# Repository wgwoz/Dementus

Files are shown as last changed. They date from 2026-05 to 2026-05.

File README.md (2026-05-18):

# Dementus
Dementus jest to projekt i prototyp urządzenia służącego do pomocy osobom z chorobami wieku starczego i po wypadkach z funkcjami umysłowo-motorycznymi. Był on realizowany w celu zgłoszenia go do Olimpiady Innowacyjności Technicznej w Mechatronice, gdzie w 2025 roku zajął 2 miejsce. 

Readme będzie stopniowo rozwijane, celem dokumentacji projektu. w międzyczasie zapraszam do dokumentacji w wersji pdf, która była utworzona na cele konkursu.

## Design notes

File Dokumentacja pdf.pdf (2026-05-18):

# DEMENTUS

## Projekt urządzenia podtrzymującego i regenerującego funkcje motoryczno-poznawcze

## Przygotowali:

Wiktor Gwoździewicz Zespół Szkół Elektronicznych Elektrycznych i Mechanicznych
Patrycja Nowak | I Liceum Ogólnokształcące im. Mikołaja Kopernika

## Pod opieką:

dr inż. Piotra Kamińskiego

Zaoraszamy również do obejżenia wideo prezentacji pod linkiem: https://drive.google.com/file/d/1-FGnG8ihYWgB2yMIkUJgleXV_v9-Wq1k/view?usp=sharing

## Spis Treści:

2) NIEPEŁNOSPRAWNOŚCI (UPOŚLEDZENIA) INTELEKTUALNE I ZABURZENIA

DEMENTUS

## Wstęp

## Cel pracy:

Aby wspomóc leczenie i rehabilitacje osób z różnego rodzaju zaburzeniami motoryczno-

poznawczymi, opracowaliśmy alternatywę dla aktualnie dostępnych na rynku tablic

sensorycznych. Nasze rozwiązanie, dzięki zastosowaniu nowoczesnych technologii, przy podejściu indywidualnym do pacjenta może przyczynić się do zwiększyć efektywność leczenia.

## Zakres pracy:

- Przeprowadzenie wywiadu środowiskowego wśród osób cierpiących na wstępne stadium choroby demencji, oraz wywiad z opiekunami osób cierpiących na demencję,
- Przedstawienie z jaki zaburzeniami motoryczno-poznawczymi możemy się spotkać wśród pacjentów,
- Przedstawienie Koncepcji projektu,
- Omówienie poszczególny elementów elektryczno-elektroniczno-mechanicznych wykorzystanych w naszym projekcie,
- Przedstawienie autorskiego kodu programu napisanego przez nas zapewniającego funkcjonalność „Dementusa”.

1

Wstęp

## Skrócony opis projektu:

Szanowni Państwo chcielibyśmy przestawić nasze unikatowe urządzenie, zwiększające motorykę pacjenta z zaburzeniami motoryczno-poznawczymi oraz co najistotniejsze podnoszące świadomość dla osób cierpiących na demencję.

Nasze projekt znamienity jest tym, że jest dedykowany indywidualnie dla pacjenta w zależności od jego preferencji. Takie podejście jest możliwe dzięki wykorzystaniu elementów elektroniczno-elektrycznych szerzej oraz szczegółowo omówionych w dalszej części pracy. Możliwość programowania oraz adaptacji kodu pod indywidualne potrzeby pacjenta. Sprawia że nasz projekt jest uniwersalny i niepowtarzalny. Większość wykorzystanych w projekcie ćwiczeń z pacjentem jest automatycznie w odpowiednim czasie wyjedzona z obudowy, a po skończonym ćwiczeniu chowana do obudowy. Ma to na celu zapewnienie odpowiedniej przestrzeni do wykonywania ćwiczenia. W obudowie znajdują się pełno silniczków, dźwigni wymagających sterowania, aby zapewnić płynnych ruch poszczególnych podzespołów.

Sercem „Dementusa” jest mikrokontroler Raspberry Pi PICO, który wykorzystując oba rdzenie kontroluje wszystkie moduły, kontroluje komunikacje po UART i SPI oraz na bieżąco monitoruje stan naładowania ogniw.

Dodatkowo zaprojektowaliśmy płytkę drukowaną, która zwiększa wytrzymałość fizyczną urządzenia, oraz pozwala na szybką wymianę modułów składowych

Ponadto wykorzystaliśmy w projekcie odtwarzacz mp3 DFPlayer mini, moduł karty SD, wyświetlacz LCD 1,8”, mostki H, drivery silników krokowych, silniki z wbudowaną przekładnią i przyciski z wbudowanym podświetleniem. Odczytuje sygnały analogowe i cyfrowe.

Szczegółowo elementy te zostały omówione w dalszej części pracy

2

Wykorzystanie kart SD z danymi pozwoliło na łatwą personalizację urządzenia do pacjenta.

Urządzenie posiada wewnętrzny akumulatory i możliwość ładowania za pomocą USB, powerbank .

Wykorzystanie druku 3d pozwoliło na szybkie prototypownie i wprowadzanie poprawek jak

i na tańszą produkcję. Zastosowanie centralnej płytki PCB z wszystkimi modułami montowanymi na goldpiny oraz zewnętrznymi elementami na wtyki JST pozwala na łatwy montaż i zmniejszenie kosztów naprawy ewentualnych uszkodzonych elementów podczas użytkowania.

Kolejność poszczególnych ćwiczeń na „Dementusie” (rodzaje ćwiczeń omówione w zasadzie działania urządzenia) jest dobierana losowo, natomiast czas trwania danego ćwiczenia w danym bloku jest nastawiany indywidualne dla poszczególnych pacjentów.

## Zasada działania urządzenia:

Nasze urządzanie w założeniu ma pomóc w maksymalnym stopniu spowolnić proces demencji. Wykonywanie kompleksowego bloku ćwiczeń ruchowo-umysłowych na naszym urządzaniu zapewni stymulację umysłu pacjenta co może przyczynić się opóźnienia demencji i tym samym zwiększy pamięć pacjenta . Nasze rozwiązanie techniczne znamienite jest tym, że jest dedykowane indywidualnie do pacjenta w zależności od jego preferencji tj. Dźwięków znanych pacjentowi, zdjęć prywatnych z przeszłości mających wywołać pozytywne myśli. Do konfiguracji naszego urządzenie niezbędne jest przeprowadzanie z pacjentem lub jego opiekunem wywiadu środowiskowego.

3

Wstęp

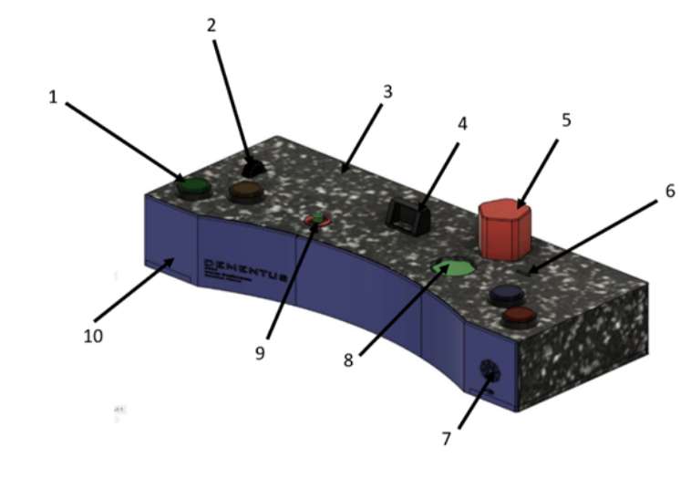
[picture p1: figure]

Dememtus 1- przyciski z wbudowanymi lampkami 4sztuki, 2-klikacz, 3-obudowa wykonana ze spieku, 4-wyświetlacz, 5-obrotowy wskaźnik zdjęć, 6-napinacz manualny, 7-głośnik, 8- spinner, 9 – skrzynia biegów 10-obudowa przednia

Przez wzgląd, że nasze urządzenie dedykowane dla osób we wstępnej fazie demencji, założyliśmy że korzystająca z naszego urządzenia osoba jeździ na wózku inwalidzkim lub będzie z niego korzystała w pozycji siedzącej. Mając powyższe na uwadze wszystkie zastosowane przyciski, drążki, dźwignie oraz manualne przyrządy do ćwiczeń, tak zostały rozmieszczone, aby w pozycji siedzącej był do nich swobodny dostęp. Na początku należy przeprowadzić z pacjentem wywiad w celu pozyskania informacji o jego zainteresowaniach, sytuacjach z życia, które przy wojują u pacjenta miłe wspomnienia. Na podstawie tych informacji zostają stworzone, pozyskane obrazy graficzne, oraz sygnały dźwiękowe.

4

Nasz pierwszy pacjent do testu urządzenia interesował się zwierzętami leśnymi (głównie ptactwem) dlatego stworzono bazę dźwięków wydawanych przez dzikie zwierzęta które usłyszymy w głośniku (7) z głośnika zostaną puszczone losowe głosy ptaków, gdzie zadaniem pacjenta będzie za pomocą obrotowego wskaźnika (5) na którym z boku będzie przymocowanych 5 zdjęć ptaków tak ustawić zdjęcie, aby wskazać odgłosy prawidłowego ptaka i potwierdzić wybór przyciskiem zielonym(1) to spowoduje że na wyświetlaczu 4 pokaże się informacja o prawidłowym bądź błędnym wskazaniu. Ma to na celu ćwiczyć koordynację ruchowo- dźwiękową oraz szukania zależności. Pragniemy w tym miejscu zaznaczyć że połączenie obrazu z dźwiękiem można zaprogramować dowolnie w zależności od preferencji pacjenta, dlatego tak istotny jest wywiad z pacjentem przed indywidualnym zaprogramowaniem „Dementusa” np. można połączyć dźwięki silnika samochodu z obrazkami konkretnych pojazdów (modeli) jeśli ktoś interesuje się motoryzacją itp. Kolejnym innowacyjnym rozwiązaniem w naszym urządzeniu jest możliwość losowego wyświetlania zdjęć z przeszłości pacjenta liczba zdjęć jaką możemy wgrać jest ograniczona tylko pojemnością karty pamięci celem nadrzędnym tego ćwiczenia jest wywołanie dobrych, pozytywnych wspomnień u pacjenta Tworząc bazę zdjęć bardzo istotne jest pozyskanie indywidulanych zdjęć dla każdego pacjenta. Zdjęcia będą wyświetlane losowo i przez pewien czas wyświetlane na wyświetlaczu (4) wraz z dźwiękiem muzyki relaksacyjnej. Ma to na celu wywołania, skoncentrowanie myśli pacjenta na pozytywnych wspomnieniach, aby choćby na chwilę oderwać się od otaczającej rzeczywistości. Kolejnym innowacyjnym elementem w naszym „Dementusie” jest dostarczenie pacjentowi rozrywki poprzez wciągnięcie pacjenta do gry polegająca na ćwiczeniu koordynacji ruchowo -wzrokowo-pamięciowej. Gra polega na losowo świecących się żarówkach w przyciskach (1) (do dyspozycji 4 przyciski z podświetleniem). Pacjent zapamiętuje kolejność zaświecania żarówek, a następnie jego zadaniem jest odtworzenie tej sekwencji poprzez naciskanie kolejnych przycisków w kolejności ich świecenia. To co istotne przyciski zostały tak rozmieszczone, aby pacjent musiał poruszać i podnieść całą rękę prawą bądź lewą zostało to wprowadzone celowo, aby zwiększyć motorykę pacjenta. Jest możliwość wyłączenia z obsługi konkretnych przycisków, jeżeli kondycja ruchowa pacjenta nie pozwala na swobodne naciśnięcie przycisku. Na początku świecą się 2 żarówki, jeśli poprawnie odtworzy się sekwencję to w dalszej kolejności randomowo świecą się 3 itd. aż do błędnej sekwencji wówczas ćwiczenie zaczyna się od nowa.

Następnym wprowadzonym przez nas rozwiązaniem jest badanie czasu reakcji pacjenta na sygnał świetlny. Odbywa się to w sposób następujący: losowo zaświeci się 1 żarówka w przycisku (1) z

5

Wstęp

czterech przycisków podświetlanych, następnie zadaniem pacjenta jest w jak najkrótszym czasie nacisnąć przycisk który się zaświecił. Program zlicza czas reakcji pacjenta i wyświetla wynik czasu reakcji na wyświetlaczu (4). Jako opiekunowie pacjenta jesteśmy w stanie sprawdzić jak szybka w danym dniu była reakcja pacjenta. Na podstawie tej informacji (czas reakcji pacjenta na bodziec) jesteśmy w stanie ocenić bieżącą kondycję pacjenta co może okazać się bardzo istotną wskazówką czy i jak choroba postępuje. Dzięki temu rozwiązaniu mamy porównanie jak pacjent poradził sobie z zadaniem w przeszłości. Umożliwi to również budowanie statystyk postępu pacjenta.

Kolejnym elementem w urządzeniu jest zaprojektowana przez nas atrapa skrzyni biegów (9), gdzie ćwiczy się koordynację ruchową poprzez właściwe wbicie biegu (urządzanie dzięki oprogramowaniu stworzonemu przez nas oraz wbudowanym głośnikom wydaje polecenie jaki bieg należy włączyć). Ponadto aby nie dezorientować pacjenta przy korzystaniu z „Dementusa” w monecie w kiedy nie korzysta się ze skrzyni biegów (9) chowa się ona do obudowy, zostało to zaprezentowane w filmiku.

Dalej, aby wzmocnić mięśnie pacjenta, jego chwyt dłonią zaprojektowaliśmy i wykonaliśmy zestaw linek (6) mocowanych na wale silniczka który możemy hamować. Ćwiczenie polega na wyciąganiu linki (wstążki) , której możemy regulować siłę oporu wyciągania, po wyciągnięciu linek można je wykorzystać do ćwiczenia zaplatania warkocza, lub ćwiczenia węzłów żeglarskich, wspinaczkowych w zależności od indywidualnych preferencji pacjenta. Po skończonym ćwiczeniu zestaw linek zostaje wciągniętych do obudowy.

Kolejnym elementem w naszym projekcie jest klikacz (2) ćwiczenie na klikaczu z założenia ma pobudzić krążenie w dłoni i palcach, przeprowadzając wywiad środowiskowy z pacjentami i ich opiekunami przed rozpoczęciem projektu. Wspominali o zaniku krążenia w palcach rąk, drętwieniu palców, dłoni. Mając powyższe na uwadze zaprojektowaliśmy ćwiczenie mające zaradzić pogłębianiu się tego zjawiska. Obrót palcem na klikaczu powoduje pobudzenie pracy mięśni, masowanie mięśni palców aby zwiększyć przepływ krwi. Klikacz (2) po skończonym ćwiczeniu chowa się (wjeżdża) do obudowy (3).

Do zwiększenia motoryki pracy dłoni zaprojektowano również spinner (8), który gdy nie jest używany znajduje się w obudowie (3), natomiast podczas pracy na nim wyjeżdża z obudowy. Spinner ma za zadanie głównie ćwiczyć ruch w nadgarstkach, przedramieniu oraz palców.

6

## O demencji i innych anormalnościach mózgu

## 1) DEMENCJA

Demencja (zespół otępienny) to grupa chorób mózgu, których wspólnym elementem jest utrata funkcji poznawczych. Według Światowej Organizacji Zdrowia demencję można zdefiniować jako zespół objawów wywołanych przez przewlekłą lub pogłębiającą się chorobę mózgu.

Demencja [16]

Otępienie różnicuje się ze względu na obszar objęcia:
- otępienie korowe: przeważają zaburzenia pamięci, zdolności wzrokowo – przestrzennych oraz funkcji językowych,
- otępienie podkorowe: przeważają spowolnienie toku myślenia oraz upośledzenie wykonywania bardziej złożonych czynności intelektualnych, przy czym funkcje językowe i umiejętności uczenia się pozostają dobrze zachowane. [1]

Możemy wyróżnić trzy poziomy demencji:
- otępienie lekkie, które cechuje się problemami w procesach poznawczych, aktywnie utrudniając osobie chorej wykonywanie codziennych czynności (chora osoba jest jednak w stanie samodzielnie funkcjonować);
- otępienie umiarkowane, przy którym samodzielne funkcjonowanie jest znacznie ograniczone, a osoba chora wymaga pomocy osób trzecich;
- otępienie głębokie, polegające na znacznym deficycie pamięci krótkotrwałej oraz zaburzeniach orientacji (osoba chora wymaga stałej opieki innych osób). [1]

7

O demencji i innych anormalnościach mózgu

Ryzyko zachorowania na demencję wzrasta wraz z wiekiem. Najczęściej dotyka ona osób po 65. roku życia, a bezpośrednią jej przyczyną jest choroba mózgu, do której doprowadzają procesy degeneracyjne w nim zachodzące.

Możliwe przyczyny i czynniki ryzyka zespołu otępiennego to:
- przebyte urazy, [1]
- problemy naczyniowe, [1]
- długotrwały, silny stres, [1]
- nieleczone choroby układu naczyniowego, [1]
- niska aktywność fizyczna i intelektualna, [1]
- nadużywanie alkoholu, [1]
- niski status społeczno – ekonomiczny, [2]
- izolacja społeczna, [2]
- niedobór witaminy D, [2]
- wysoki poziom białka C – reaktywnego, [2]
- upośledzenie słuchu, [2]
- cukrzyca, [2]
- depresja, [2]
- palenie tytoniu, [2]
- gen apolipoproteiny E. [2]

Rodzaje demencji
Najczęstsza forma demencji to choroba Alzheimera.[1] Jest ona spowodowana nieprawidłowym gromadzeniem się białek w komórkach mózgowych i wokół nich. W efekcie zmniejsza się liczba przekaźników chemicznych zdolnych do wysyłania sygnałów między neuronami. Poziom acetylocholiny jest szczególnie niski u osób dotkniętych tą chorobą.[3] Następuje stopniowe pogarszanie się wzroku, dotyku, słuchu, poczucia świadomości. Osoby chore jako jeden z pierwszych objawów najczęściej zauważają pogorszenie się pamięci. [1] Leczenie tej choroby polega na leczeniu objawów stosując odpowiednie leki. Bardzo istotne jest zapewnienie choremu

8

spokoju, komfortu i poczucia bezpieczeństwa. Ważne jest też stosowanie ćwiczeń umysłowych i pamięciowych. [34]

Otępienie czołowo – skroniowe (choroba Picka) występuje na skutek zmian w płatach skroniowych

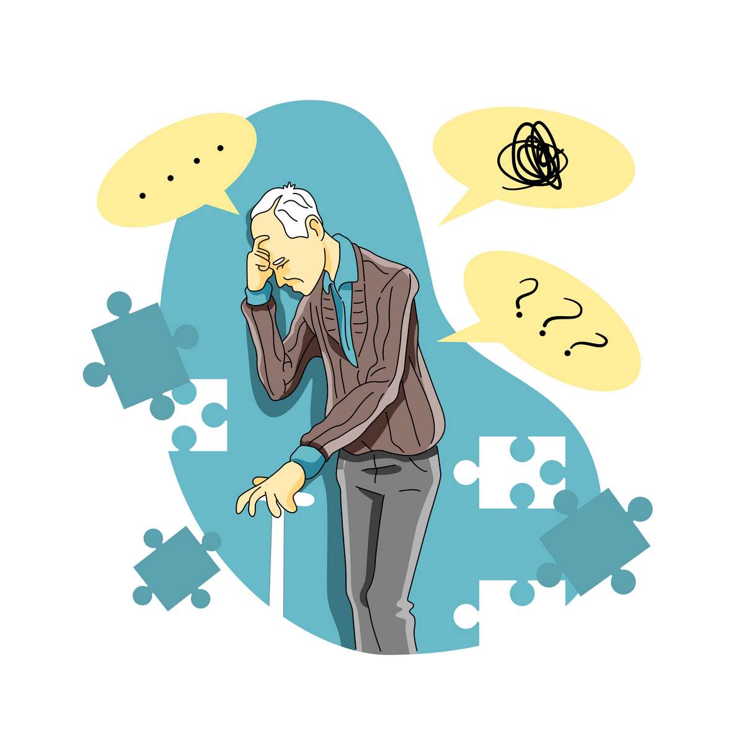
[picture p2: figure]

i czołowych mózgu.[3] W przypadku postaci czołowej schorzenia występują zaburzenia w obrębie zachowania i osobowości, a w przypadku postaci skroniowej – zaburzenia w obrębie wysławiania się. Często obie postacie występują jednocześnie. Osoby cierpiące na tę postać demencji mogą przejawiać zachowania agresywne, być nieuprzejme. Może również wystąpić stopniowa utrata zdolności zapamiętywania imion, trudności ze zrozumieniem wypowiedzi czy znaczenia poszczególnych słów.[1] Nie ma możliwości rozpoczęcia leczenia przyczynowego choroby, w związku z czym leczenie polega na łagodzeniu nieprzyjemnych i uciążliwych objawów chorobowych oraz ćwiczeniu umysłu i pamięci chorego. [35]

Demencja naczyniowa jest wywoływana przez uszkodzone naczynia krwionośne w mózgu, przez co niemożliwe jest dostarczenie odpowiedniej ilości krwi zawierającej tlen i składniki odżywcze do komórek mózgowych. Przyczyną tego rodzaju demencji może być udar. [3] Objawy mogą zostać zaobserwowane bezpośrednio po udarze lub w pewnym okresie po jego wystąpieniu. Charakterystycznym objawem jest znaczne pogorszenie się percepcji. Demencja naczyniowa często występuje w kombinacji z chorobą Alzheimera[1], a leczenie tych dwóch chorób wygląda bardzo podobnie. Przy demencji naczyniowej również stosuje się leczenie farmakologiczne oraz ćwiczenia umysłowe i pamięciowe. [36]

9

Otępienie czołowo-skroniowe [17]

O demencji i innych anormalnościach mózgu

Otępienie z ciałami Lewy’ego występuje gdy ciała Lewy’ego, czyli patologiczne białka, gromadzą się w mózgu, w wyniku czego niszczony jest ośrodkowy układ nerwowy. Jest to choroba postępująca, której charakterystycznymi objawami są drżenie kończyn, problemy z przełykaniem, upadki i halucynacje wzrokowe oraz koszmary senne.[3] Występują zaburzenia w poruszaniu się, zachowaniu i myśleniu. Często występuje w połączeniu z chorobą Parkinsona, Alzheimera i/lub demencją naczyniową.[1] W przypadku tej choroby wszystkie grupy symptomów wymagają zastosowania odrębnego leczenia obejmującego farmakoterapię oraz metody niefarmakologiczne (stymulacja poznawcza, ćwiczenia pamięci, trening orientacji w przestrzeni, rozwiązywanie krzyżówek, układanie puzzli itp.) [37]

Choroba Creutzfeldt-Jakoba jest powodowania przez priony. Jest śmiertelną chorobą mózgu, której pierwszymi objawami są pogorszenie pamięci, brak koncentracji i zmienione zachowanie. Choroba jest agresywna i gwałtowna – w późniejszych stadiach doprowadza do osłabienia kończyn, utraty wzroku i śpiączki.[1] Ważną rolę w opiece nad chorym odgrywa odpowiednia dieta. Jakość życia poprawiają również odpowiednie ćwiczenia intelektualne. [38]

Rodzaje demencji [18]

We wczesnych fazach choroby często jest ona trudna do wychwycenia zarówno przez osobę chorą, jak i jej najbliższe otoczenie. Bardzo ważna jest obserwacja seniorów i zwracanie szczególnej uwagi na pierwsze objawy ostrzegawcze, takie jak zapominanie o bieżących wydarzeniach, trudności z czynnościami i sytuacjami wcześniej nie sprawiającymi trudności, brak orientacji w

10 czasie i miejscu, gubienie przedmiotów, ogólne zmiany w osobowości,[1] zadawanie tych samych pytań w krótkich odstępach czasu, nagłe zmiany nastrojów.[3]

W przypadku zauważenia niepokojących objawów, należy zgłosić się do lekarza podstawowej opieki zdrowotnej. Lekarz zanalizuje stan pacjenta, a następnie skieruje do specjalisty lub do szpitala.[3] Nie istnieje lek, który wyleczy demencję – jest ona chorobą nieuleczalną. W przypadku tej choroby podaje się jedynie leki, które zwiększają poziom acetylocholiny – substancji przekaźnikowej w układzie nerwowym, która odpowiada m.in. za procesy pamięciowe.[4] Bardzo ważnym elementem leczenia jest również dbanie, aby osoba chora pozostawała aktywna intelektualnie poprzez ćwiczenia pamięciowe i umysłowe (krzyżówki, rebusy, czytanie książek).[1]

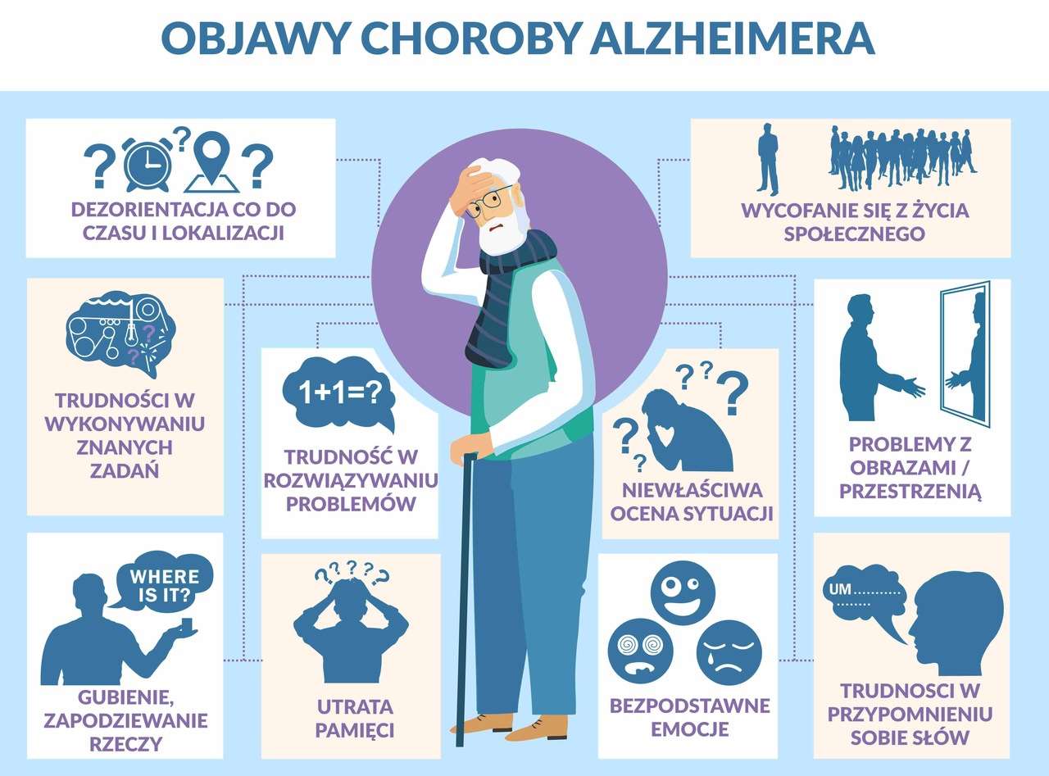
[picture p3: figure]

Objawy choroby Alzheimera [19]

## 2) NIEPEŁNOSPRAWNOŚCI (UPOŚLEDZENIA) INTELEKTUALNE I ZABURZENIA ROZWOJOWE

Niepełnosprawność intelektualna to zaburzenie rozwojowe, które polega na obniżeniu funkcji intelektualnych wraz z deficytem na polu zachowań adaptacyjnych.[5] Objawia się najczęściej trudnościami w nauce i porozumiewaniu się, wykonywaniu czynności dnia codziennego oraz zyskiwaniu kompetencji społecznych. [6]

11

O demencji i innych anormalnościach mózgu

Niepełnosprawność intelektualna [20]

Termin ,,upośledzenie umysłowe” jest uważane w środowisku psychologów i pedagogów za stygmatyzujący, pomimo że nazwa ta nadal oficjalnie funkcjonuje w medycynie. Uważa się, że utrwala ona negatywne stereotypy, w związku z czym apeluje się, aby w nazewnictwie pozamedycznym używać terminu ,,niepełnosprawność intelektualna”.[6]

Niepełnosprawność umysłową można badać pod kątem:
- kliniczno-medycznym: badane jest wtedy wrodzone bądź istniejące od wczesnego dzieciństwa obniżenie poziomu rozwoju intelektualnego, [6]
- psychologiczno-społecznym: badane są wtedy głównie konsekwencje dla umiejętności społecznych i interpersonalnych danej osoby oraz jej samodzielne funkcjonowanie w społeczeństwie. [6]

Klasyfikacja zaburzeń rozwoju intelektualnego:
- upośledzenie w stopniu lekkim:
Stanowi najłagodniejszą formę niedorozwoju umysłowego, odpowiada poziomowi inteligencji osoby w wieku 10 – 12 lat. Zdiagnozowane osoby mają zazwyczaj problem z pamięcią, abstrakcyjnym myśleniem, spostrzegawczością, wyobraźnią. Dominuje myślenie konkretno – obrazowe, występują problemy z myśleniem przyczynowo – skutkowym, porównywaniem. Proces socjalizacji przechodzi na ogół dobrze. Następuje opóźniony rozwój motoryczny: dzieci z lekkim upośledzeniem później uczą się siadać i chodzić. [5],[6]

12

- upośledzenie w stopniu umiarkowanym:
Odpowiada poziomowi inteligencji osoby w wieku 6 – 9 lat. Osoba upośledzona ma duże problemy z tempem uczenia się, skupieniem uwagi. Jest w stanie opanować jedynie podstawy pisania, czytania i liczenia. Rozwój motoryczny opóźniony, dziecko siada w wieku ok. 2 lat, chodzi w wieku ok. 3 lat. Osoba zdiagnozowana jest bardzo wrażliwa, słabo kontroluje swoje emocje. W zachowaniu występują skrajności: dziecko może być apatyczne, spokojne, niesprawiające żadnych problemów lub może być nadpobudliwe, nieposłuszne i niszczyć przedmioty. [5],[6]
- upośledzenie umysłowe w stopniu znacznym:
Odpowiada poziomowi inteligencji osoby w wieku 3 – 6 lat. Występują poważne problemy z motoryką, mówieniem, spostrzegawczością, pamięcią, koncentracją. Potrafi koncentrować się głównie na przedmiotach wyróżniających się np. kolorem lub służących do zaspokajania potrzeb. Nie w pełni kontroluje emocje, przekazuje uczucia w sposób raczej prosty. Potrafi realizować swoje podstawowe potrzeby, ale wymaga nieustannej pomocy opiekuna. [5],[6]
- upośledzenie umysłowe w stopniu głębokim:
Odpowiada poziomowi inteligencji osoby w wieku 2 – 3 lat. Zdiagnozowane osoby nie są w stanie się uczyć, opanowują kilka wyrazów i poleceń. Przekazują tylko najprostsze komunikaty emocjonalne. Nie są w stanie realizować nawet podstawowych potrzeb, wymagają nieustannej opieki. [5],[6]

13

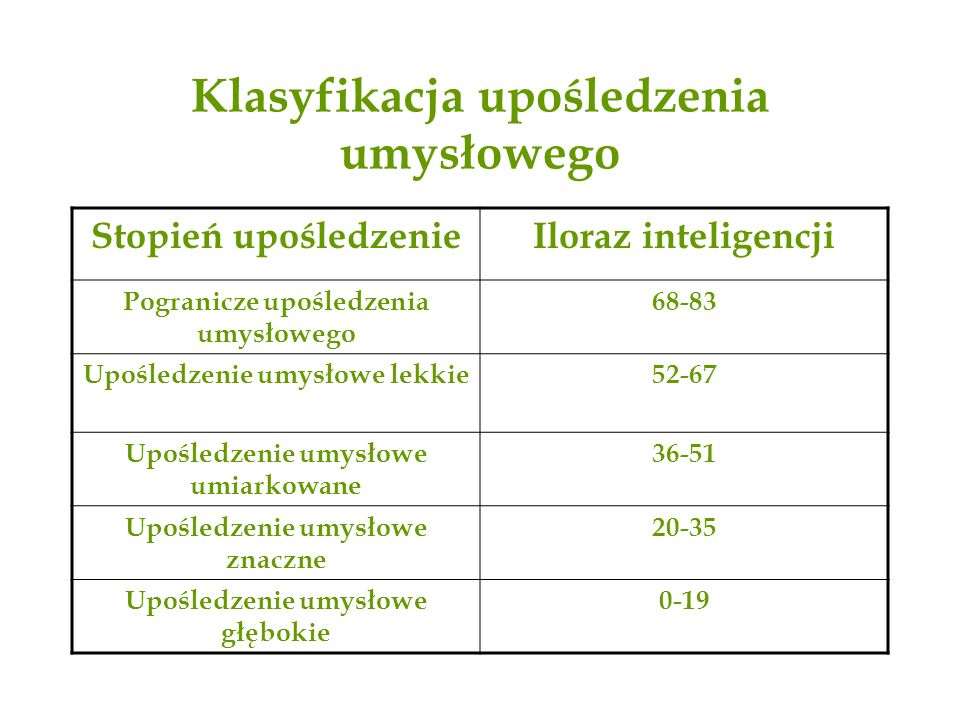
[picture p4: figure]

Klasyfikacja upośledzenia umysłowego [21]

O demencji i innych anormalnościach mózgu

Przyczyny upośledzeń umysłowych:
- pierwotne – uwarunkowane mutacjami genetycznymi, które powstały w okresie płodowym. Powstaje na skutek aberracji chromosomowych, czyli zmian w ich liczbie lub strukturze. Powoduje choroby genetyczne jak zespół Downa, zespół Pataua czy zespół kociego krzyku oraz choroby metaboliczne o podłożu genetycznym, np. fenyloketonurię lub galaktozemię. [7]
- wtórne – uwarunkowane działaniem czynników uszkadzających. Zazwyczaj mowa o działaniu czynników, które uszkadzają korę mózgową w okresie płodowym. Takie czynniki to zarówno silne leki zażywane przez ciężarną kobietę jak i zakażenia wirusami niebezpiecznymi dla płodu (wirus różyczki, ospy wietrznej, cytomegalii). [7]

Diagnoza dzieci i młodzieży [22]

Upośledzenia umysłowe w stopniu znacznym i głębokim można zauważyć już we wczesnym okresie dzieciństwa – u takich osób mowa wykształca się bardzo późno lub nie wykształca się wcale. Przy cięższych stopniach upośledzenia występują również zaburzenia dodatkowe, takie jak wady wzroku, słuchu, narządów wewnętrznych oraz zaburzenia motoryczne. [7]

Upośledzenie umysłowe można rozpoznać posługując się testami psychologicznymi mierzącymi poziom intelektualny oraz zaburzenia w rozwoju umiejętności potrzebnych w codziennym życiu.

14

Upośledzenie może stwierdzić psycholog konsultując się z logopedą i niekiedy również neurologiem i psychiatrą. Diagnozę stawia się zazwyczaj u dzieci w wieku 3 – 5 lat.[7]

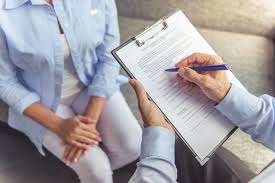
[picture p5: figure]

Diagnoza psychologiczna [23]

Wybrane rodzaje zaburzeń rozwojowych:

- zespół Downa – osobę z zespołem Downa można rozpoznać po charakterystycznym wyglądzie. Obserwuje się np. płaski profil twarzy, skośne ustawienie szpar powiekowych, kącik oka przykryty fałdem skórnym, małe, nisko osadzone uszy, nadmiar skóry na karku, małe, szerokie dłonie i stopy, opuszczone kąciki ust. U noworodków można ponadto stwierdzić zmniejszone napięcie mięśniowe i nadmierną ruchomość w stawach. [8]

U zdecydowanej większości osób z zespołem Downa występują zaburzenia poznawcze oraz niepełnosprawność intelektualna w stopniu lekkim lub umiarkowanym. Organizm takich osób wykazuje tendencję do przedwczesnego starzenia się i demencji. [8] Leczenie tej choroby ma charakter objawowy, ważna jest aktywność fizyczna ze względu na skłonność do otyłości. Dzieci z zespołem Downa mogą uczęszczać do przedszkoli wraz z rówieśnikami, jednak dojrzałość szkolną osiągają później niż zdrowe dzieci oraz wymagają nauczania zindywidualizowanego. Rozwija się również myślenie abstrakcyjne. [8]

15

O demencji i innych anormalnościach mózgu

Cechy zespołu Downa [29]

- zespół Angelmana („zespół szczęśliwej kukiełki”) – do 3. miesiąca życia rozwój dziecka przebiega prawidłowo, co utrudnia lub uniemożliwia zdiagnozowanie choroby. Pomiędzy 6. miesiącem a 2. rokiem życia zauważalne są pierwsze objawy, takie jak trudności w karmieniu, obniżone napięcie mięśniowe, opóźniony rozwój psychoruchowy. U części chorych występują napady padaczki, wygórowane odruchy głębokie, częste ślinienie się, zez, nadmierna wrażliwość na wysoką temperaturę. [9]

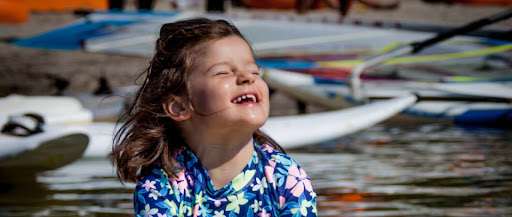
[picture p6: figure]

Zespół Angelmana [25]

Dzieci z zespołem Angelmana charakteryzują się pogodnym usposobieniem, charakterystycznym uśmiechem, zaburzonymi ruchami kończyn i napadami śmiechu, przez co często są określane jako „dzieci marionetki”. Występuje również upośledzenie umysłowe, sprawiające problem w komunikowaniu się z dzieckiem. [9] Przy zespole Angelmana stosuje się leczenie objawowe,

16 polegające na rehabilitacji, treningu logopedycznym mowy oraz stosowaniu technik komunikacji niewerbalnej. Stosowana jest również farmakoterapia. [33]

- zespół Jacobsena – do objawów należą m.in. deformacje czaszki, wysokie, wydatne czoło, asymetryczna twarz, hiperteloryzm, opadanie powiek, krótki nos, cienkie palce rąk i stóp, wąska górna warga. Choroba powoduje opóźnienie umysłowe. Charakterystyczną cechą zespołu Jacobsena są zaburzenia krzepnięcia krwi oraz niedobór płytek krwi, co skutkuje zwiększonym ryzykiem krwawień. [10]

17

Przyczyny zespołu Angelmana [24]

O demencji i innych anormalnościach mózgu

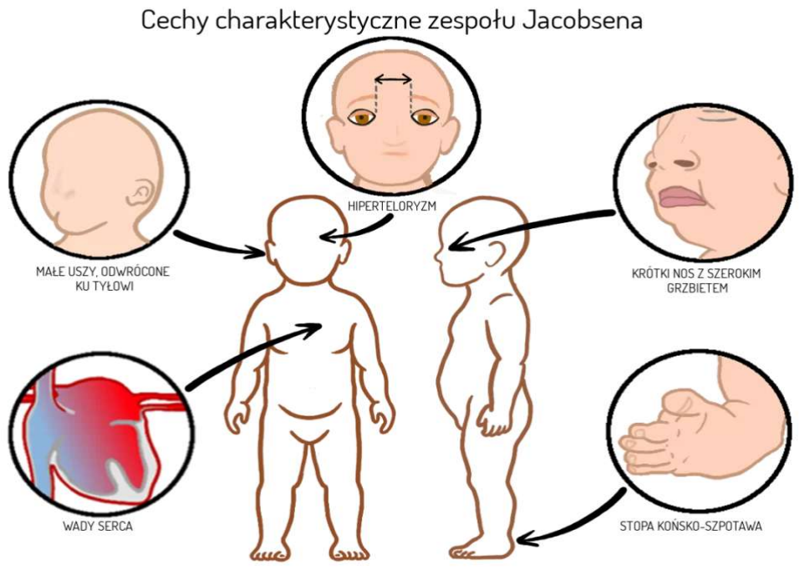
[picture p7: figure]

Cechy zespołu Jacobsena [26]

Około 20% chorych dzieci umiera do 2. roku życia na skutek wad serca i występowania krwawień.
[10] Leczenie powinno być interdyscyplinarne, ukierunkowane na występujące problemy. Część pacjentów wymaga przetoczeń płytek lub leczenia farmakologicznego czy chirurgicznego. Ważna jest rehabilitacja i właściwa edukacja. [10]
- choroba Burneville’a (stwardnienie guzowate) – należy do grupy chorób nerwowo-skórnych, charakteryzuje się obecnością zmian skórnych oraz guzów. Zmiany zachodzą w obrębie układu nerwowego, narządu wzroku, serca, płuc, nerek i wątroby. [11]

Jako pierwsze objawy najczęściej zauważane są bezbarwne znamiona na tułowiu i kończynach. Około 3. roku życia pojawiają się charakterystyczne guzki Pringle’a na twarzy i nosie. Później pojawiają się płaskie włókniaki czoła, włókniaki okołopaznokciowe rąk i stóp oraz ogniska skóry szaragrynowej. [11]

U 85% chorych występują powikłania neurologiczne – są one następstwami zmian w mózgu i objawiają się m.in. padaczką, upośledzeniem umysłowym, zaburzeniami osobowości. [11] Leczenie polega na łagodzeniu objawów. Stosuje się leki przeciwpadaczkowe, leczenie chirurgiczne lub stymulacje nerwu błędnego. Przy upośledzeniu umysłowym i zaburzeniach osobowości stosuje się ćwiczenia umysłowe. [39]

18

- autyzm dziecięcy – zaburzenie rozwoju i funkcjonowania ośrodkowego układu nerwowego. Objawia się dużymi trudnościami w komunikowaniu uczuć i potrzeb oraz w tworzeniu relacji międzyludzkich. Z rozwojem autyzmu łączą się też zaburzenia w funkcjonowaniu poszczególnych obszarów mózgu – stwierdza się podwyższony poziom serotoniny oraz zaburzenia związane z innymi neuroprzekaźnikami w mózgowiu. [12]

Autyzm można rozpoznać już u niemowlęcia – nie nawiązuje ono kontaktu wzrokowego, nie gaworzy, nie reaguje na swoje otoczenie. Gdy dziecko jest starsze zaczyna mieć problemy z zabawą z rówieśnikami, nie toleruje dotyku, ma problemy z akceptowaniem zmian w rutynie. Dziecko zazwyczaj jest pochłonięte „swoim światem”. [12] Leczenie polega na terapii behawioralnej, muzykoterapii czy terapii logopedycznej. Wprowadza się również elementy terapii behawioralno – poznawczej pomagającej dziecku w komunikacji z innymi ludźmi. [40]

- alkoholowy zespół dziecięcy (FAS) – spowodowany jest kontaktem dziecka z alkoholem w okresie płodowym. Wyodrębnia się różne rodzaje uszkodzeń spowodowanych piciem alkoholu przez matkę w ciąży:
- objawy fizyczne i fizjologiczne – w szczególności charakterystyczne są zmiany w wyglądzie twarzy, czyli cienka górna warga, małe, szeroko rozstawione oczy, opadające powieki, małe czoło, zdeformowane, nisko osadzone uszy. Ponadto występuje też niski wzrost, problemy z odpornością. [13]

19

O demencji i innych anormalnościach mózgu

Cechy FAS [27]

- objawy neurologiczne – opóźnienie umysłowe, trudności w nauce, zaburzenia koncentracji, problem z pojmowaniem pojęć abstrakcyjnych. [13]
- objawy behawioralno-emocjonalne – problem z nawiązywaniem kontaktów, nadpobudliwość, agresja, problemy z adaptacją, skłonności do depresji i uzależnień.[13]

Nie ma lekarstwa na FAS. Wsparcie dziecka chorego polega na jak najwcześniejszej diagnozie oraz dobór odpowiedniego, indywidualnego toku nauki. [41]

Leczenie:
Upośledzenia umysłowego nie da się wyleczyć, nie istnieją na nie żadne leki. Najważniejsza jest pełna, szczegółowa diagnoza, a następnie w oparciu o nią przygotowanie indywidualnego planu edukacyjnego i rehabilitacyjnego. Pomocna jest również odpowiednio prowadzona terapia. [7],[6]

Wychowanie i opieka nad dzieckiem z niepełnosprawnością intelektualną to dla rodziców ogromne wyzwanie. Nie mogą oni oczekiwać od dziecka czegoś ponad jego możliwości, ale jednocześnie nie mogą dziecka wyręczać, tak, aby zdobyło ono umiejętności potrzebne do samodzielnego, dorosłego życia. To samo dotyczy nauczycieli dziecka w placówkach wychowawczych. Bardzo ważne jest znalezienie już istniejących zasobów dziecka (np. empatia, inicjatywa do działania) i podkreślanie ich, unikanie podkreślania braków dziecka, budowanie pozytywnego ale realistycznego obrazu jego możliwości, unikanie krytyki zarówno dziecka jak i rodziców, oraz udzielanie im wsparcia emocjonalnego. [14]

## 3) WYPADKI

Bardzo częstymi skutkami wypadków (samochodowych, upadków, uderzeń) są urazy głowy. Wiele ofiar takich urazów zmaga się z problemami zdrowotnymi, takimi jak choroby neurologiczne i psychiczne, które mogą występować bezpośrednio po urazie lub ujawniać się z biegiem lat.[30]

Przykładowe choroby neurologiczne występujące po urazach głowy:
- encefalopatia pourazowa: zespół objawów neurologicznych będących skutkiem zmian w mózgu spowodowanych urazami głowy. Charakterystyczne objawy to problemy z mową, zaburzenia

20 pamięci, problemy z koordynacją ruchów, dezorientacja przestrzenna i czasowa. Osoby dotknięte tą chorobą doświadczają dużych trudności w codziennym funkcjonowaniu, m.in. w aktywnościach związanych z pracą i życiem społecznym.[30] Leczenie koncentruje się na zarządzaniu objawami i poprawie jakości życia chorego poprzez stosowanie rehabilitacji poznawczej, farmakoterapii oraz psychoterapii. [42]
- pourazowa padaczka: objawia się ona zmianami w funkcjonowaniu mózgu, które występują nagle i krótkotrwale. Zmiany te prowadzą do nagłej utraty przytomności, drgawek i innych objawów. Osoby chore muszą regularnie stawiać się na wizyty kontrolne u lekarza neurologa.[30] Leczenie uzależnione jest od stopnia uszkodzenia mózgu i występujących objawów. Stosuje się terapię za pomocą farmaceutyków, jednak jest to kwestia dyskusyjna. Zastosowanie ma również leczenie operacyjne. [43]

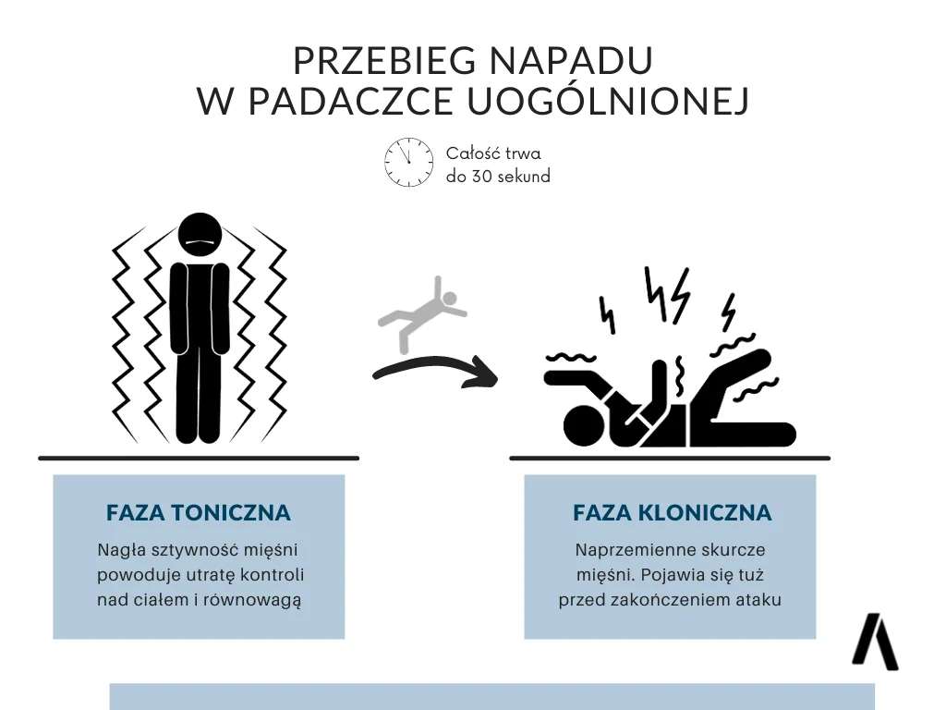
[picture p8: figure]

Przebieg napadu padaczki [31]

21

O demencji i innych anormalnościach mózgu

Przeciwwskazania dla osób z padaczką [31]

Przykładowe zaburzenia psychiczne po urazach głowy:
- zespół stresu pourazowego: występuje po doświadczeniu traumatycznego wydarzenia. Objawia się m.in. koszmarami sennymi, lękami i unikaniem sytuacji i miejsc przypominających traumę.[30] Najlepsze efekty leczenia uzyskuje się poprzez terapię poznawczo – behawioralną. Inne metody leczenia to terapia ekspozycyjna, EMDR i farmakoterapia. [44]
- depresja: uraz może spowodować zmiany chemiczne w mózgu powodujące zaburzenia depresyjne. Ponadto mogą się one pojawić w wyniku trudności z powrotem do codziennych czynności oraz zmian w relacjach z innymi. [30]
- zaburzenia lękowe: uraz głowy może prowadzić do niepokoju, fobii, nadmiernego lęku i zaburzeń obsesyjno – kompulsywnych. [30]
- zaburzenia nastroju: część osób po urazach głowy doświadcza huśtawek nastroju; zmiany z jednego skrajnego stanu emocjonalnego na drugi. [30]
- zaburzenia psychotyczne: mogą objawiać się one halucynacjami, omamami lub myślami paranoidalnymi. [30]

22

- zaburzenia funkcji poznawczych: widoczne są w formie problemów z pamięcią, koncentracją, planowaniem i podejmowaniem decyzji. [30]

Leczenie i pomoc dla osób po wypadkach:
Wypadki, których konsekwencją są urazy głowy często powodują u osób poszkodowanych zmianę całego dotychczasowego życia. Bardzo ważne jest wspieranie takich osób przez ich rodzinę i przyjaciół, którzy muszą dostosować się do nowej rzeczywistości, co wymaga dużej cierpliwości, elastyczności i zaangażowania.[32]

Ważne jest niedopuszczenie do izolacji społecznej takiej osoby. Aby temu zapobiec, należy starać się jak najlepiej zrozumieć istotę choroby i sytuacji drugiej osoby. Zmiana rzeczywistości ofiary wypadku jest dla niej szczególnie trudna, ponieważ nagle jest ona zależna fizycznie i emocjonalnie od innych.[32]

Konsekwencjami fizycznymi i psychicznymi urazów może być niemożność wykonywania danych czynności, co wpływa na sferę zawodową poszkodowanej osoby. Częstym rozwiązaniem jest dla takich osób przebranżowienie się lub praca zdalna.[32]

Najważniejsze jednak w rekonwalescencji takich osób jest podjęcie odpowiednio dobranej rehabilitacji i terapii.[32]

23

O demencji i innych anormalnościach mózgu

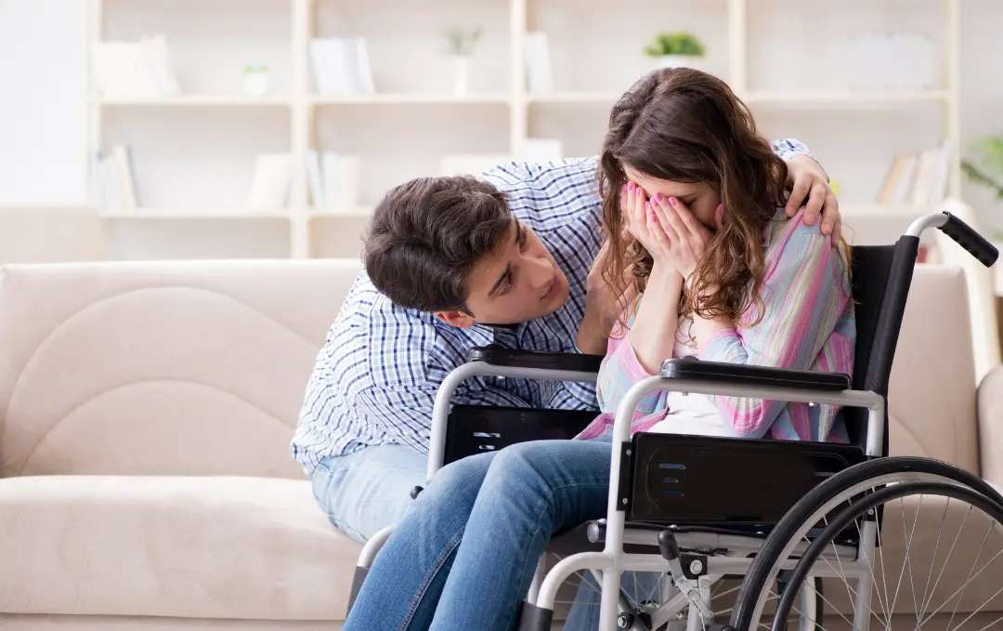
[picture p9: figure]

Urazy głowy [32]

## 4) TABLICE SENSORYCZNE I MANIPULACYJNE

Popularne w terapii osób z niepełnosprawnościami stały się tablice sensoryczne i manipulacyjne. Przynoszą one wiele korzyści, pomagają rozwijać zdolności poznawcze, motoryczne i emocjonalne. Stymulują zmysły, sprzyjają rozwojowi mózgu i poprawiają koncentrację. [15]
Wyposażone w takie elementy jak np. przyciski, koła zębate i klawisze, angażują niepełnosprawną osobę i pozwalają na poprawę jej stanu oraz lepszą komunikację. [15]

Tablica manipulacyjna [28]

24

## BIBLIOGRAFIA wstępu teoretycznego

### 1. Przyczyny demencji oraz czynniki ryzyka | Care Experts 22.10.2024

### 2. Jest lista 15 czynników zwiększających ryzyko demencji (medonet.pl) 22.10.2024

### 3. To może być demencja | Pacjent 24.10.2024

### 4. Demencja starcza - objawy i leczenie (medonet.pl) 24.10.2024

### 5. Niepełnosprawność intelektualna – Wikipedia, wolna encyklopedia 27.10.2024

6. Upośledzenie umysłowe (niepełnosprawność intelektualna) – objawy, przyczyny, leczenie - PoradnikZdrowie.pl 27.10.2024
7. Upośledzenie umysłowe (oligofrenia) – kiedy mamy z nim do czynienia? Przyczyny, objawy 29.10.2024

### 8. Zespół Downa (trisomia 21. chromosomu): przyczyny, objawy i leczenie | Pediatria -

mp.pl 29.10.2024

### 9. Zespół Angelmana - objawy, przyczyny, leczenie i rokowania 29.10.2024

### 10. Zespół Jacobsena - Centrum Medyczne Meavita | Kraków, Rusznikarska 14 29.10.2024

### 11. Stwardnienie guzowate | Neurologia - mp.pl 29.10.2024

### 12. Autyzm dziecięcy – objawy, przyczyny, terapia przy zaburzeniach autystycznych

30.10.2024

### 13. FAS (alkoholowy zespół płodowy) - czym jest, jak powstaje i jakie są objawy zespołu

FAS? - apteka Olmed 30.10.2024

### 14. Wsparcie rodziców uczniów z niepełnosprawnością intelektualną - ePedagogika

30.10.2024

### 15. Tablica manipulacyjna dla dzieci - co to jest? - PLN Design 30.10.2024

### 16. Demencja starcza - etapy choroby | Seni24.pl 10.11.2024

### 17. Otępienie czołowo-skroniowe = chorobliwy brak słów - MentalExpert 10.11.2024

### 18. Demencja starcza - rodzaje demencji - otępienie naczyniowe - objawy - Projekt Damy

Radę 10.11.2024

### 19. Choroba Alzheimera - leczenie online | Avigon 10.11.2024

### 20. Niepełnosprawność intelektualna - jej przyczyny, objawy i podział 10.11.2024

### 21. Miej uszy i oczy, serce i dusze szeroko otwarte - ppt pobierz 10.11.2024

25

BIBLIOGRAFIA wstępu teoretycznego

### 22. Diagnoza dzieci i młodzieży - mgr Kamila Tagliaferro

psycholog/psychoterapeuta/superwizor 10.11.2024

### 23. Diagnoza psychologiczna | Umów wizytę w MindHealth 11.11.2024

### 24. Zespół Angelmana - objawy, przyczyny, leczenie i rokowania 11.11.2024

### 25. Fundacja Angelmana 11.11.2024

### 26. Zespół Di George'a - Objawy - Diagnostyka - Leczenie - Centrum Medyczne Meavita |

Kraków, Rusznikarska 14 11.11.2024

### 27. Alkohol niszczy życie jeszcze przed narodzinami. Dzieci z FAS mają szereg problemów

11.11.2024

### 28. TABLICA MANIPULACYJNA EXPEDITION - Nature 11.11.2024

### 29. Zespół Downa – Lekarka Bajkopisarka 11.11.2024

### 30. Choroby neurologiczne i psychiczne po urazach głowy - Fundacja Moc Pomocy

12.11.2024

### 31. Padaczka - podstawy przed podjęciem aktywności fizycznej 13.11.2024

### 32. Wpływ urazów głowy na funkcjonowanie społeczne i zawodowe - Fundacja Moc

Pomocy 13.11.2024

### 33. Zespół Angelmana - Portal Fizjoterapeuty 20.11.2024

### 34. Choroba Alzheimera | Przyczyny, objawy, leczenie 20.11.2024

### 35. Choroba Picka (Pick′s disease, PiD) - objawy, diagnoza i leczenie – 20.11.2024

### 36. Otępienie naczyniopochodne | Psychiatria - mp.pl 20.11.2024

### 37. Otępienie z ciałami Lewy’ego – objawy, rozpoznanie, leczenie - Poradnik Gemini

20.11.2024

### 38. Choroba Creutzfeldta-Jakoba (CJD) – przyczyny, pierwsze objawy i sposoby leczenia |

Żywienie ma znaczenie 20.11.2024

### 39. Stwardnienie guzowate – przyczyny, objawy, leczenie - Poradnik Gemini 20.11.2024

### 40. Co to jest autyzm? Jakie są jego przyczyny i czy da się go wyleczyć? - aptelia.pl

20.11.2024

### 41. Alkoholowy Zespół Płodowy (zespół FAS) - objawy i leczenie | Nowa Farmacja

20.11.2024

### 42. Przewlekła encefalopatia pourazowa: objawy i leczenie 20.11.2024

### 43. Padaczka pourazowa: przyczyny, objawy i sposoby leczenia 20.11.2024

### 44. Zespół stresu pourazowego (PTSD) - objawy i sposoby leczenia 20.11.2024

26

## Założenia projektu

Aby wspomóc leczenie i rehabilitacje osób z różnego rodzaju zaburzeniami motoryczno-poznawczymi, chcieliśmy opracować alternatywę dla aktualnie dostępnych na rynku tablic sensorycznych, która dzięki zastosowaniu nowoczesnych technologi zwiększa efektywność leczenia.
Aktywacja większej ilości zmysłów poprzez światła dźwięki i obrazy pozwala na większe zaangażowanie mózgu, a wykorzystanie kart SD z danymi pozwoli na łatwą personalizację urządzenia do pacjenta.
Urządzenie powinno być w solidnej obudowie, którą można łatwo transportować, dla wygody użytkowania, urządzenie powinno posiadać wewnętrzne akumulatory i możliwość ładowania z istniejącej infrastruktury.
Szerokie zastosowanie druku 3d pozwoli na szybkie prototypowanie i wprowadzanie poprawek jak i na tanią produkcję małoskalową
Zastosowanie centralnej płytki PCB z wszystkimi modułami montowanymi na goldpiny, a zewnętrznymi elementami na wtyki JST pozwala na łatwy montaż i zmniejszenie kosztów naprawy uszkodzonych elementów.

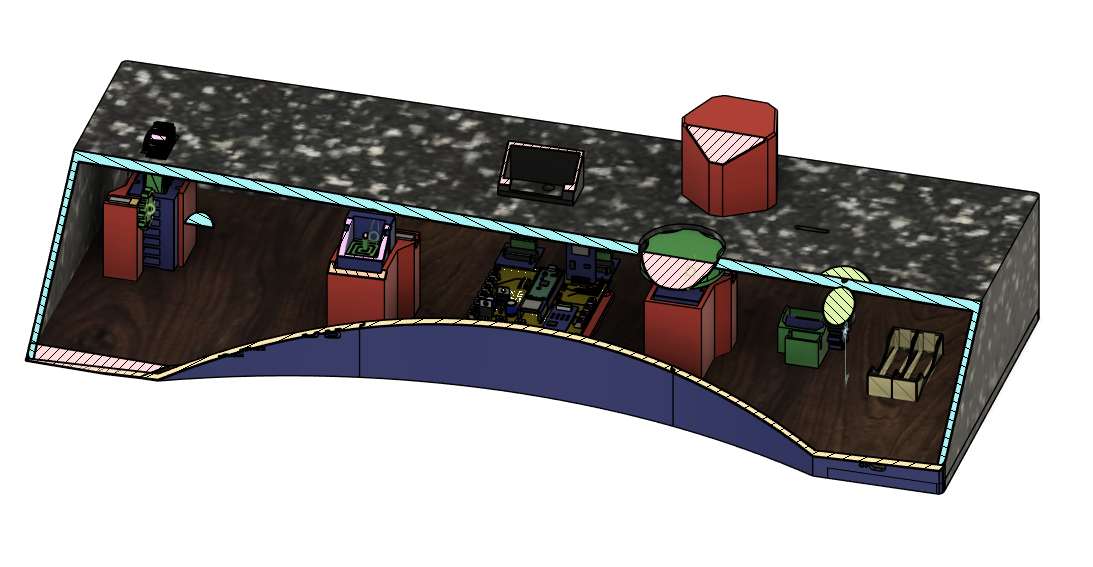
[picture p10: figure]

27

Omówienie ważniejszych elementów składowych

## Omówienie ważniejszych elementów składowych

## Elektronika

Raspberry Pi PICO

Mikrokontroler od fundacji Raspberry łączy szerokie możliwości z niską ceną i łatwością programowania. W tym projekcie wykorzystano dostępne interfejsy komunikacyjne UART i SPI, wejścia analogowe oraz wszystkie piny cyfrowe. Dzięki dwurdzeniowemu procesorowi kontrola stanu baterii może być wykonywana na drugim rdzeniu nie obciążając pierwszego rdzenia i nie zaburzając pracy głównego programu. Z szerokiej gamy dostępnych na PICO języków programowania, użyte zostało C++ w środowisku deweloperskim Arduino. Głównymi powodami wyboru był szeroki i łatwy dostęp do bibliotek oraz kompilacja programu, zwiększająca wydajność.

DFPlayer Mini

Odtwarzacz plików dźwiękowych komunikuje się z mikrokontrolerem za pomocą UART’u, dodatkową zaletą jest przyjmowanie kart micro SD z plikami ułożonymi w foldery, co pozwala na łatwą personalizację dźwięków do pacjenta. Wbudowany wzmacniacz umożliwia bezpośrednie podpięcie głośnika.

28

ST 7735

Kolorowy wyświetlacz LCD o rozdzielczości 160x128 i przekątnej 1.8” Komunikuje się po protokole SPI, w tym urządzeniu wyświetla zarówno obrazy mające na celu przywołać wspomnienia jak i tekst, zwykle wynik w jednej z gier. Obrazy przechowywane są na osobnej karcie micro SD, dzięki czemu również można łatwo spersonalizować urządzenie.

Li-ion 18650

Dla zapewnienia mobilności urządzenia dodano do niego akumulatory. Ze względu na swoją popularność wybrane zostały popularne akumulatory Litowo-jonowe 18650 połączone szeregowo w formie 2S. W połączeniu z modułem USB-C możliwe jest ładowanie urządzenia popularnymi ładowarkami do telefonów.

29

Omówienie ważniejszych elementów składowych

Silnik szczotkowy z wbudowaną przekładnią

Jako główny napęd elementów mechanicznych zastosowano silniki szczotkowe 6v z wbudowaną przekładnią ograniczającą prędkość obrotową do 30obr/min. To rozwiązanie niweluje niebezpieczeństwo związane z szybko obracającymi się ośkami. Dodatkowo w porównaniu do wykorzystywanych w pierwszych prototypach silników krokowych, do sterowania nimi wymagane jest prawie trzykrotnie mniej pinów mikrokontrolera. Do sterowania silnikami wykorzystano moduły sterowania silnikami krokowymi bazujące na układzie L298D

Przyciski

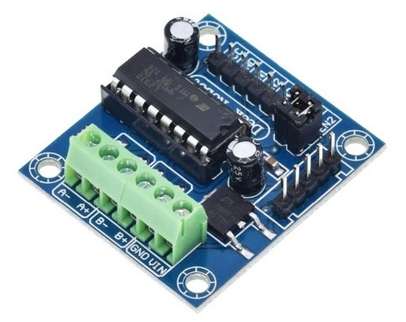
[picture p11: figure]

Jako główny środek interakcji z elektroniką wykorzystano cztery silniki z wbudowanym podświetleniem. Duży rozmiar, jaskrawe kolory i wystawanie przycisków pozwala na łatwe ich używanie a podświetlenie jest dodatkową metodą porozumiewania z pacjentem. Do obsługi podświetlenia wykorzystano moduł bazujący na układzie ULN2003D

30

## Mechanika

Zespół kół zębatych

Dla całego urządzenia przyjęto standard kół zębatych o module 3 z kołem zamontowanym na silniku mającym 10 zębów. Większość urządzeń posiada parę koło zębate-listwa zębata, dzięki czemu element jest w stanie poruszać się góra-dół po szynach. Od dołu jego ruch limituje podstawa a od góry ogranicznik wbudowany w stojak

Fidget spinner

Jest to zabawka poruszająca się na łożysku, dzięki czemu pacjent może ją swobodnie obracać. Wykorzystując parametry wydruku 3d, element obracający ma masę skupioną na swoim obrzeżach co pozwala na maksymalne zachowanie pędu.

31

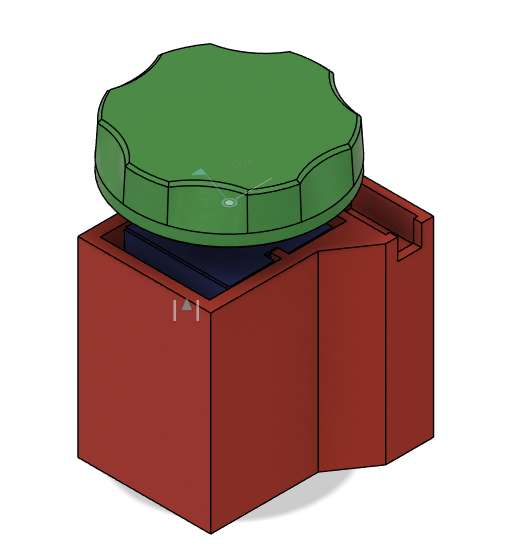
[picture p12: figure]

Omówienie ważniejszych elementów składowych

Skrzynia biegów

Ta zabawka skupia się na precyzyjnych zdolnościach manualnych. Jest ona zminiaturyzowaną wersją drążka zmiany biegów w samochodzie. Drążek znajduje się na spiralnej sprężynie dzięki czemu sam powraca do pozycji środkowej, z kolei w górnej części obudowy znajduje się sprężyna o skomplikowanym kształcie umożliwiająca „wrzucenie” każdego z biegów.

Klikacz

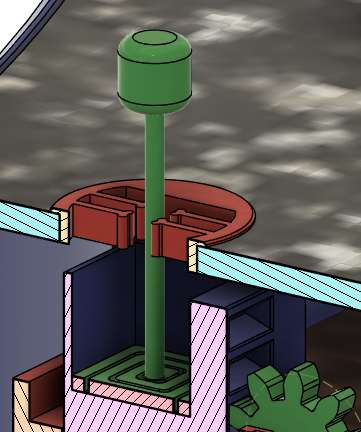
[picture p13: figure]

Jest zabawką rozbudowującą siłę mięśni palców. Została ona wykonana w technologii print in place, co oznacza, że elementy ruchome i sprężyny zostały wydrukowane naraz a dzięki geometrii są nierozdzielnie połączone. Obracanie pokrętłem kompresuję sprężynę i generuje dźwięki klikania.

32

Montaż płyty bazowej

Płyta bazowa została zamontowana do obudowy za pomocą kątowników wsuwanych do specjalnych kanałów utworzonych poprzez połączenie elementów montażowych z obudową. Elementy te zabezpieczają płytę przez przesuwaniem się do góry a także mają miejsce na śrubę zabezpieczającą kątowniki. Dla zwiększenia siły gwintu i uproszczenia topologii, otwór został nagwintowany po wydruku.

33

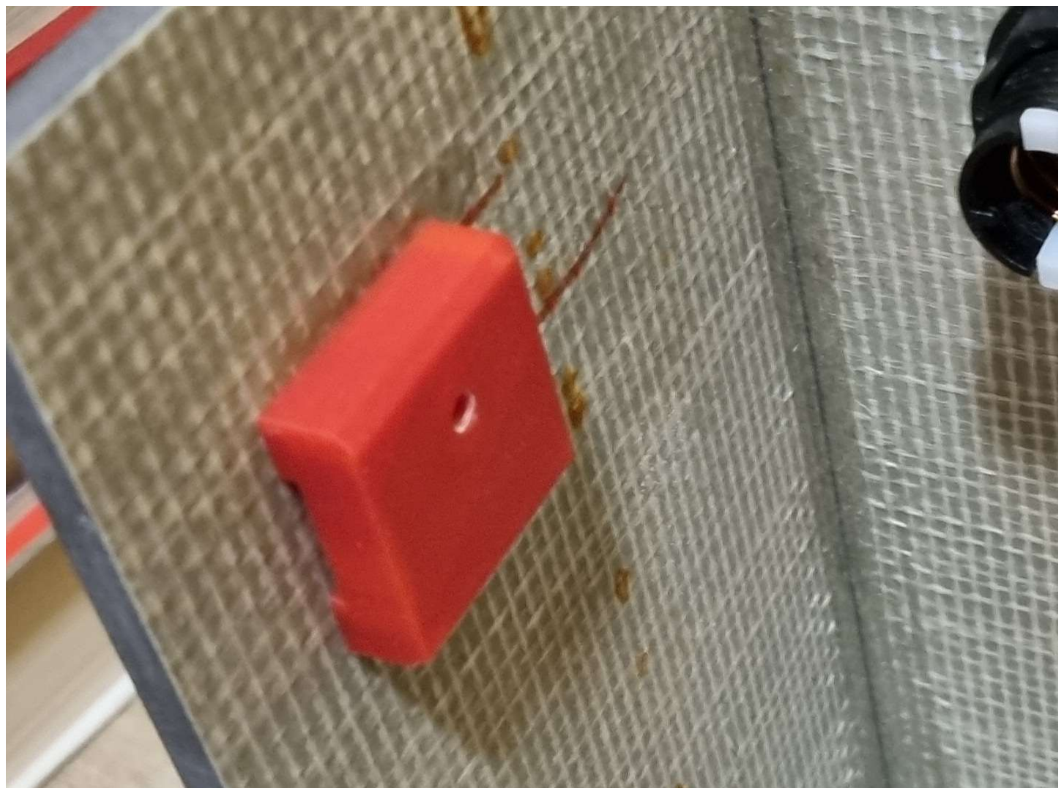
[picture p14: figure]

Omówienie ważniejszych elementów składowych

Podstawka płytki PCB

Płytka PCB została umieszczona na podstawce wydrukowanej w 3D, dzięki czemu jest lżejsza i łatwiejszą w wykonaniu niż tradycyjne podstawki bazujące na metalowych dystansach. Zabezpiecza ona płytkę i ułatwia jej montaż/demontaż

Obudowa

Obudowa została wykonana z czterech arkuszy wyciętej strumienie wody płyty kamieniopodobnej. Zapewnia to aspekty estetyczne oraz wytrzymałość

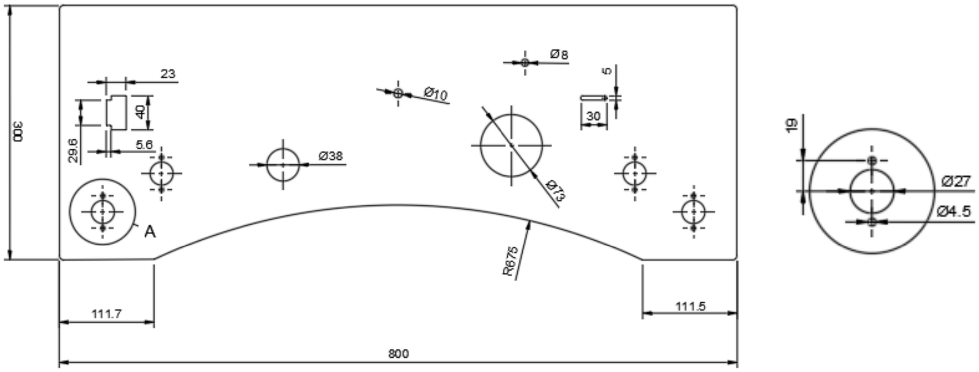
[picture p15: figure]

34

Panel Przedni

Panel przedni został wykonany z trzech elementów aby umożliwić zmieszczenie go na polu roboczym drukarki 3D. Do najważniejszych cech panelu zaliczyć można zazębienie na linii podziału zapobiegające przedostawaniu się światła i utrudniających podważenie paneli; Zestaw otworów umożliwiających lepsze przekazywanie dźwięków przez głośnik; oraz otwór na kabel ładowania.

35

Schemat elektryczny

## Schemat elektryczny

## Omówienie

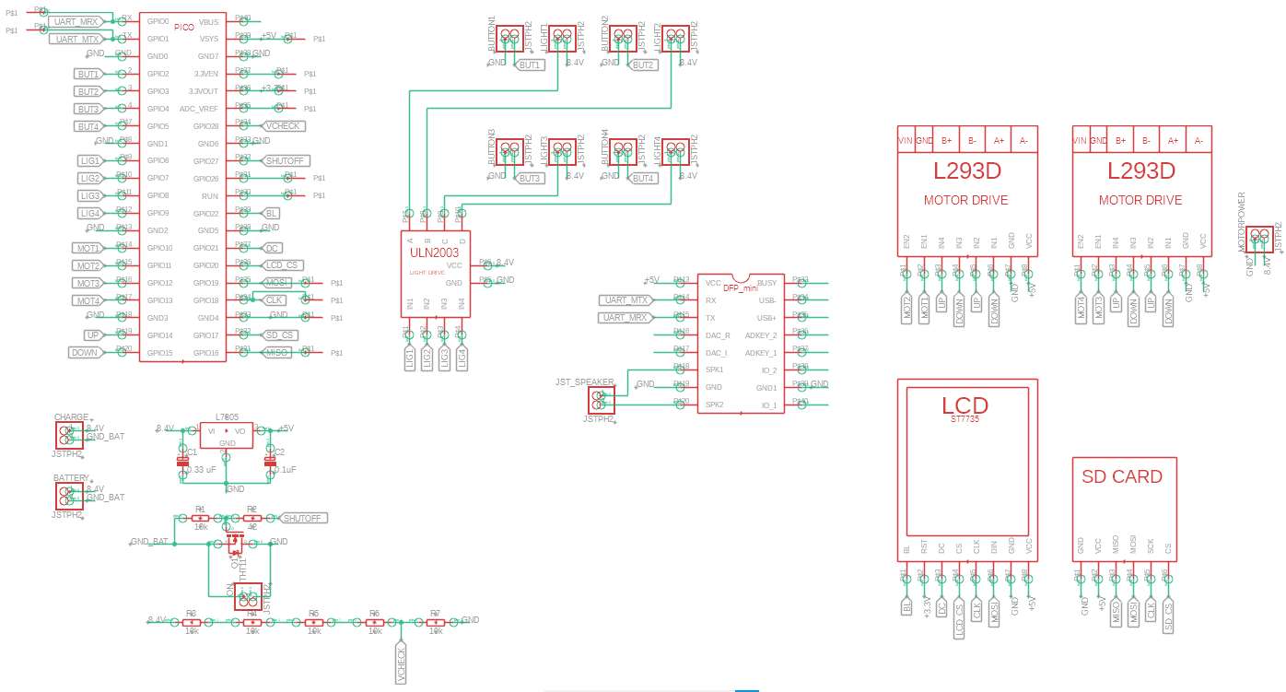
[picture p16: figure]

Schemat elektryczny został podzielony na segmenty, bazujące na modułach. Aby nie zaciemniać rysunku, w większości przypadków zamiast przewodów zastosowano etykiety. W lewym górnym rogu widzimy mikrokontroler. Pod nim znajduje się segment zasilania. Na prawo od niego segment przycisków, pod którym jest segment dźwiękowy. Po prawej stronie jest segment sterowania silnikami, a pod nim segment wyświetlacza.

36

## Mikrokontroler

Mikrokontroler zasilany jest z napięcia stabilizowanego +5V. Sam stabilizuje napięcie do poziomu +3.3V.

37

Schemat elektryczny

## Zasilanie

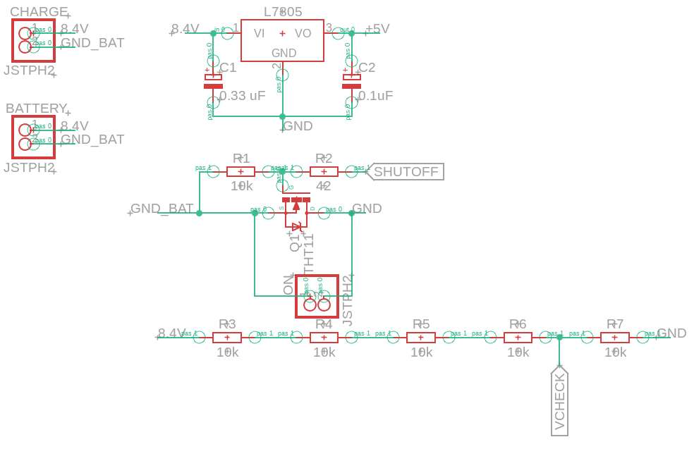
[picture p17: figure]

Sekcja zasilania posiada trzy gniazda JST. Po lewej stronie widzimy dwa z nich, któe są względem siebie równoległe. Pierwsze z nich jest podłączone do modułu ładowania, a drugie do akumulatorów. Na górze widać stabilizator napięcia, który zamienia napięcie 8.4V potrzebne silnikom i lampkom na 5V potrzebne elektronice. Układ pod nim odpowiada za załączenie i wyłączenie urządzenia.
Tranzystor mosfet oddziela bazę baterii od głównej bazy pozostałych urządzeń. Przycisk podpięty do gniazda JST ON pozwala zewrzeć tranzystor co łączy bazy i uruchamia urządzenie, następnie mikrokontroler przez etykietę SHUTOFF załącza tranzystor. Jeżeli wyjście SHUTOFF zostanie zmienione w stan wysokiej impedancji, tranzystor, a za tym całe urządzenie, zostanie wyłączone. Na dole znajduje się dzielnik napięcia, dzięki któremu mikrokontroler za pomocą wejścia analogowego VCHECK mierzy poziom naładowania baterii i może w razie potrzeby ostrzec o jej niskim poziomie lub wyłączyć urządzenie.

38

## Przyciski i dźwięk

Każdy przycisk jest podpięty do mikrokontrolera dwoma stykami JST. Jeden odpowiada za styki a drugi za podświetlenie.
Styki obsługiwane są bezpośrednio przez mikrokontroler, z kolei podświetlenie za pomocą modułu UNL2003D, który oryginalnie służy do sterowania pięcioprzewodowym silnikiem krokowym. Moduł ten po podaniu stanu wysokiego na wejście podłącza odpowiadające mu wyjście do masy. DFPlayer mini z mikrokontrolerem komunikuje się za pomocą UART’a. Poza zasilaniem wychodzi z niego tylko gniazdo JST na głośnik. Inne przydatne funkcje jak pin busy są niewykorzystywane ze względu na ograniczenie ilości wejść mikrokontrolera i używane są ich alternatywy UART.

39

Schemat elektryczny

## Silniki

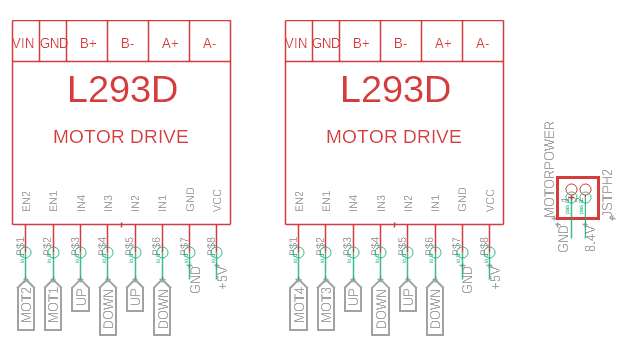
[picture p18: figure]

Silniki są sterowane za pomocą dwóch modułów bazujących na układach L293D. Układy te posiadają dwa mostki H każdy. Dla zaoszczędzenia pinów, każdy input parzysty i nieparzysty jest odpowiednio z sobą zwarty do wyjść sterownika UP i DOWN, co oznacza że każdy silnik w danej chwili może się ruszać tylko w jednym kierunku. Wejścia EN wybierają które z silników w danej chwili mają się ruszać, a UP i DOWN, w którym kierunku. Styk JST MOTORPOWER służy przekazaniu masy i napięcia z baterii do styków VIN i GND w górnej części modułu. Są one oddzielone od tych w dolnej części.

40

## Wyświetlacz

Wyświetlacz i karta SD używają wspólnej magistrali SPI z osobnym pinem chip select. Służy ona do odczytu bitmap zapisanych na karcie pamięci i wysyłaniu ich, oraz innych poleceń rysowania, do wyświetlacza. Ponadto Występują piny BL, który pozwala na wyłączenie podświetlenia ekranu, co może się przydać gdy to nie na ekranie powinna zostać skupiona uwaga, oraz DC, który mówi ekranowi, czy aktualnie wysyłane do niego są polecenia czy dane.

41

Płytka PCB

## Płytka PCB

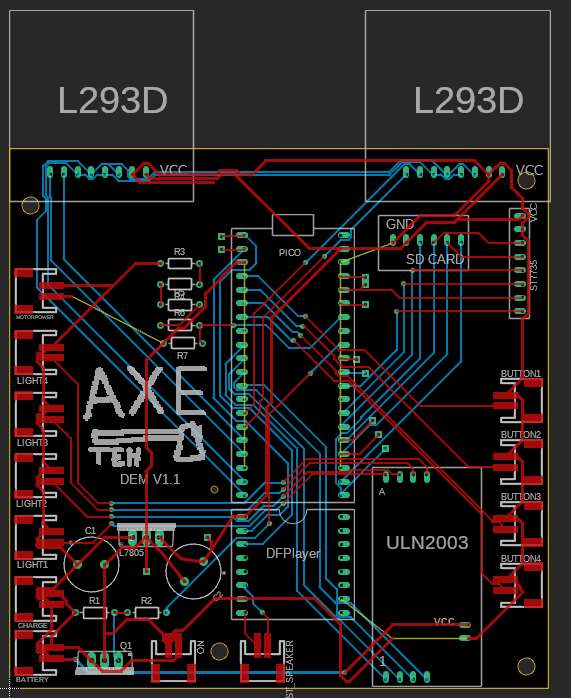
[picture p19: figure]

Wszystkie komponenty elektroniczne zostały ze sobą połączone za pomocą dwuwarstwowej płytki PCB o wymiarach 100x100mm. Warstwa górna została zaznaczona na czerwono, a dolna na niebiesko. Na powyższym rysunku nie widać masy, aby ścieżki były bardziej widoczne. Warstwa dolna została użyta tylko do poprowadzenia ścieżek, które się krzyżują. Wszystkie elementy są przylutowane od góry. Aby zapewnić łatwy montaż modułów na niektórych z nich konieczne było

42 przelutowanie pinów z góry na spód. Ścieżki zasilania mają szerokość 20mil, a pozostałe 10 mil. Płytka mocowana jest do podstawki czterema otworami o średnicy 3mm. Aby ułatwić ewentualny rozwój projektu, zasilanie oraz magistrale komunikacyjne posiadają dodatkowe wyprowadzenie nie podpięte do niczego.

43

Kod programu

## Kod programu

## Omówienie

Struktura plików
Projekt posiada dwie karty SD. Na karcie wykorzystywanej w współpracy z ekranem znajdują się mapy bitowe obrazów mających na celu pobudzać wspomnienia pacjenta. Karta w odtwarzaczu muzyki posiada trzy foldery. Na pierwszym z nich znajdują się dźwięki systemowe, dźwięki uruchomienia i wyłączenia, ostrzeżenie o stanie baterii oraz nuty odpowiadające przyciskom. Drugi folder posiada dźwięki odpowiadające obrazom na graniastosłupie pięciokątnym, wykorzystywane one są do gry w dopasowanie. Trzeci folder posiada utwory muzyczne i odgłosy budzące wspomnienia. Są one wykorzystywane razem z wyświetlaczem LCD.

Rdzeń 1
Rdzeń pierwszy po inicjalizacji wszystkich peryferiów generuje ziarno generatora liczb pseudolosowych używane do generowania sekwencji zabaw i innych elementów losowych. Następnie losuje jedną z dostępnych zabaw:

Zabawka mechaniczna
Poprzez aktywację jednego z silników wysuwa się jedna z zabawek, by pacjent mógł się nią pobawić. Po określonym czasie chowie się z powrotem.

Gra dopasowanie
Odpalony zostaje jeden z dźwięków z folderu drugiego. Zadaniem pacjenta jest dopasowanie dźwięku do jednego z obrazów na graniastosłupie. Gdy mu się to uda, zagrany zostaje dźwięk sukcesu. Po trzech dobrych dopasowaniach gra się kończy

Gra pamięć
Gra zaczyna się od zapalenia się jednej z lampek i zagrania odpowiadającego jej dźwięku. Zadaniem pacjenta jest naciśnięcie tego samego przycisku. Rezultatem tego będzie zagranie dźwięku sukcesu, a następnie zapalenie tej samej lampki, po której zapali się losowo wybrana inna. W tej pętli powstaje coraz dłuższa sekwencja, którą pacjent ma za zadanie zapamiętać i odtworzyć. W razie pomyłki zagrany zostaje dźwięk porażki, a wynik zostaje wyświetlony na ekranie.

Gra czas reakcji
Gra zaczyna się zapaleniem wszystkich lampek a następnie odliczaniem utworzonym przez ich systematyczne gaśnięcie. Gdy wszystkie lampki zgasną po chwili jedna z nich się zapali. Zadaniem Pacjenta jest jak najszybsze naciśnięcie odpowiedniego przycisku. Czas reakcji zostanie wyświetlony na ekranie.

44

Przywołanie wspomnień
Na ekranie wyświetla się obraz, oraz zostaje odtworzony dźwięk, których zadaniem jest przywołanie wspomnień. Po zakończeniu dźwięku urządzenie przechodzi do kolejnej gry.

Rdzeń 2
Zadaniem drugiego rdzenia jest wyłączenie urządzenia w odpowiedniej chwili. Najpierw włącza on je poprzez podanie stanu wysokiego na wyjście SHUTOFF, a potem sprawdza czy występują warunku by je przełączyć w stan wysokiej impedancji. Jednym z nich jest spadnięcie napięcia na wejściu analogowym VCHECK poniżej 1.1V, drugim naciśnięcie wszystkich 4 przycisków naraz przy graniastosłupie obróconym maksymalnie w prawo. Dodatkowo jeżeli napięcie spadnie poniżej 1.25V, zagrany zostanie dźwięk informujący o niskim poziomie baterii.

## Treść

1 /****Dementus v1.0****\
2 //
3 //Podziękowania dla użytwonika Makuna i zespołu adafruit za biblioteki do modułów użytych w tym kodzie
4 //Aby projekt działał poprawnie, musisz zmodyfikować bibliotekę Adafruit ST7735
5 //W tym celu znajdź plik Adafruit_ST7735.cpp i w okolicach połowy zjadź teks " Black tab, change MADCTL color filter
6 //if ((options == INITR_BLACKTAB) || (options == INITR_MINI160x80)) {"
7 //następnie wklej ""_colstart = 2; _rowstart = 1; "" wewnątrz funkcji if.
8 //
9 // analogRead() osiąga wartości od 0 do 1023
10 //
11 // digitalRead(BUTTON_1)==1 oznacza NIEwciśnięty przycisk 12 //
13 */
14
15 //definicje pinów
16
17 //Uart do komunikacji z DFPlayer mini 18 #define UART_RX 0
19 #define UART_TX 1
20
21 //kierunki ruchu silników 22 #define UP 15
23 #define DOWN 14
24
25 //analog pins

45

Kod programu

26 #define POTENTIOMETER 26 //pin analogowy, sprawdza ustwienie pokrętła z ptakami
27 #define VOLTAGE 28 | // pin analogowy, sprawdza napięcię baterii przez
dzielnik
28 #define KEEP_ON 27 | // utrzymuje mosfet a przez to urządzenie włączone.
by wyłączyć urządzenie zmień tryb na input
29
30 //Obsługa wyświetlacza LCD
31 #define LCD_BACKLIGHT 22
32 #define LCD_DC 21
33 #define LCD_CS 20
34 #define TFT_CS 20
35 #define TFT_RST 37
36 #define TFT_DC 21
37 #define TFT_BACKLIGHT 22 38 #define SerialDebugging true 39
40 //chip select karty SD
41 #define SD_CS 17
42
43 //Spiny do komunikacji SPI 44 #define MOSI 19
45 #define MISO 16
46 #define CLK 18
47
48 //
49 // stałe użytkownika
50 #define maxGameLenght 100 // sztucznie ogranicza długość gry w pamięć 51

52 //rzeczy potrzebne do działania wyświetlacza LCD
53 //biblioteki
54 #include <Adafruit_GFX.h> // Core graphics library
55 #include <Adafruit_ST7735.h> // Hardware-specific library for ST7735 56 #include <SPI.h>
57 #include <SD.h>
58

### 59 Adafruit_ST7735 tft = Adafruit_ST7735(TFT_CS, TFT_DC, TFT_RST);//obiekt

wyświetlacza
60

61 // oznaczenie kolorów podstawowych
62 const uint16_t Display_Color_Black = 0x0000; 63 const uint16_t Display_Color_Blue = 0x001F; 64 const uint16_t Display_Color_Red = 0xF800; 65 const uint16_t Display_Color_Green = 0x07E0; 66 const uint16_t Display_Color_Cyan = 0x07FF;

46

67 const uint16_t Display_Color_Magenta = 0xF81F; 68 const uint16_t Display_Color_Yellow = 0xFFE0; 69 const uint16_t Display_Color_White = 0xFFFF;
70
71 // główne kolory tekstu i tła
72 uint16_t Display_Text_Color = Display_Color_Black;
73 uint16_t Display_Backround_Color = Display_Color_Blue;
74
75 // zakladamy, że wyświetlacz jest wyłączony aż go zinicjalizujemy 76 bool isDisplayVisible = false;
77
78 // rozmiar buffera dla tekstu. Basic strlen("d hh:mm:ss") = 10 79 const size_t MaxString = 16;
80
81 #define BUFFPIXEL 20

### 82 void bmpDraw(char *filename, uint8_t x, uint8_t y) { //komentarze autora

biblioteki nie tłumaczone dla funkcji
83 File bmpFile;
84 | int bmpWidth, bmpHeight; | // W+H in pixels
85 | uint8_t bmpDepth; | // Bit depth (currently must be 24)
86 | uint32_t bmpImageoffset; | // Start of image data in file
87 | uint32_t rowSize; | // Not always = bmpWidth; may have
padding
88 | uint8_t sdbuffer[3 * BUFFPIXEL]; | // pixel buffer (R+G+B per pixel)

### 89 uint8_t buffidx = sizeof(sdbuffer); // Current position in sdbuffer

90 | boolean goodBmp = false; | // Set to true on valid header parse
91 | boolean flip = true; | // BMP is stored bottom-to-top
92 int w, h, row, col;
93 uint8_t r, g, b;
94 uint32_t pos = 0, startTime = millis();
95 if ((x >= tft.width()) || (y >= tft.height())) return; 96 Serial.println();
97 Serial.print("Loading image '");
98 Serial.print(filename);
99 Serial.println('\'');
100 // Open requested file on SD card
101 if ((bmpFile = SD.open(filename)) == NULL) { 102 Serial.print("File not found");
103 return;
104 }
105 // Parse BMP header
106 if (read16(bmpFile) == 0x4D42) { // BMP signature
107 Serial.print("File size: ");
108 Serial.println(read32(bmpFile));
109 | (void)read32(bmpFile); | // Read & ignore creator bytes
110 bmpImageoffset = read32(bmpFile); // Start of image data
111 Serial.print("Image Offset: ");

47

Kod programu

112 Serial.println(bmpImageoffset, DEC); 113 // Read DIB header
114 Serial.print("Header size: ");
115 Serial.println(read32(bmpFile));
116 bmpWidth = read32(bmpFile);
117 bmpHeight = read32(bmpFile);
118 | if (read16(bmpFile) == 1) { | // # planes -- must be '1'
119 bmpDepth = read16(bmpFile); // bits per pixel
120 Serial.print("Bit Depth: ");
121 Serial.println(bmpDepth);
122 if ((bmpDepth == 24) && (read32(bmpFile) == 0)) { // 0 = uncompressed
123 | goodBmp = true; | // Supported BMP format
-- proceed!
124 Serial.print("Image size: ");
125 Serial.print(bmpWidth);
126 Serial.print('x');
127 Serial.println(bmpHeight);
128 | // | BMP rows are padded (if needed) to 4-byte boundary
129 rowSize = (bmpWidth * 3 + 3) & ~3;
130 // If bmpHeight is negative, image is in top-down order.
131 // This is not canon but has been observed in the wild.
132 if (bmpHeight < 0) {
133 bmpHeight = -bmpHeight;
134 flip = false;
135 }
136 // Crop area to be loaded
137 w = bmpWidth;
138 h = bmpHeight;
139 if ((x + w - 1) >= tft.width()) w = tft.width() - x; 140 if ((y + h - 1) >= tft.height()) h = tft.height() - y; 141 // Set TFT address window to clipped image bounds
142 tft.setAddrWindow(x, y, x + w - 1, y + h - 1);
143 for (row = 0; row < h; row++) { // For each scanline... 144 // Seek to start of scan line. It might seem labor-145 // intensive to be doing this on every line, but this 146 // method covers a lot of gritty details like cropping 147 // and scanline padding. Also, the seek only takes
148 // place if the file position actually needs to change
149 // (avoids a lot of cluster math in SD library).
150 if (flip) // Bitmap is stored bottom-to-top order (normal BMP) 151 pos = bmpImageoffset + (bmpHeight - 1 - row) * rowSize;
152 else // Bitmap is stored top-to-bottom
153 pos = bmpImageoffset + row * rowSize;
154 if (bmpFile.position() != pos) { // Need seek?
155 bmpFile.seek(pos);
156 buffidx = sizeof(sdbuffer); // Force buffer reload 157 }

48

158 for (col = 0; col < w; col++) { // For each pixel... 159 // Time to read more pixel data?
160 if (buffidx >= sizeof(sdbuffer)) { // Indeed
161 bmpFile.read(sdbuffer, sizeof(sdbuffer));
162 buffidx = 0; // Set index to beginning
163 }
164 // Convert pixel from BMP to TFT format, push to display 165 b = sdbuffer[buffidx++];
166 g = sdbuffer[buffidx++];
167 r = sdbuffer[buffidx++];
168 tft.pushColor(tft.color565(r, g, b)); 169 } // end pixel
170 | } | // end scanline
171 Serial.print("Loaded in ");
172 Serial.print(millis() - startTime); 173 Serial.println(" ms");
174 } // end goodBmp
175 }
176 }
177 bmpFile.close();
178 if (!goodBmp) Serial.println("BMP format not recognized.");
179 }
180 // te funkcje służą odczytaniu 16 i 32 bitowych typów plików z karty sd 181 // BMP data is stored little-endian, Arduino is little-endian too.
182 // May need to reverse subscript order if porting elsewhere.
183 uint16_t read16(File f) {
184 uint16_t result;
185 ((uint8_t *)&result)[0] = f.read(); // LSB
186 ((uint8_t *)&result)[1] = f.read(); // MSB 187 return result;
188 }
189 uint32_t read32(File f) {
190 uint32_t result;
191 ((uint8_t *)&result)[0] = f.read(); // LSB 192 ((uint8_t *)&result)[1] = f.read();
193 ((uint8_t *)&result)[2] = f.read();
194 ((uint8_t *)&result)[3] = f.read(); // MSB 195 return result;
196 }
197

198 // rzeczy potrzebne do działania DFPlayer mini 199 #include <DFMiniMp3.h> // biblioteka
200

201 class Mp3Notify; // klasa powiadomień
202

49

Kod programu

203 typedef DFMiniMp3<HardwareSerial, Mp3Notify> DfMp3; //obiekt będzie używał hardwarowego UART i klasy powiadomień
204
205 // instancja obiektu
206 DfMp3 dfmp3(Serial1);
207 class Mp3Notify {
208 public:
209 static void PrintlnSourceAction(DfMp3_PlaySources source, const char *action) {
210 if (source & DfMp3_PlaySources_Sd) {
211 Serial.print("SD Card, ");
212 }
213 if (source & DfMp3_PlaySources_Usb) { 214 Serial.print("USB Disk, ");
215 }
216 if (source & DfMp3_PlaySources_Flash) { 217 Serial.print("Flash, ");
218 }
219 Serial.println(action);
220 }
221 static void OnError([[maybe_unused]] DfMp3 &mp3, uint16_t errorCode) { 222 // sprawdź DfMp3_Error by znaleść znaczenia błędów
223 Serial.println();
224 Serial.print("Com Error ");
225 Serial.println(errorCode);
226 }
227 static void OnPlayFinished([[maybe_unused]] DfMp3 &mp3, [[maybe_unused]] DfMp3_PlaySources source, uint16_t track) {
228 Serial.print("Play finished for #");
229 Serial.println(track);
230 }
231 static void OnPlaySourceOnline([[maybe_unused]] DfMp3 &mp3, DfMp3_PlaySources source) {
232 PrintlnSourceAction(source, "online");
233 }
234 static void OnPlaySourceInserted([[maybe_unused]] DfMp3 &mp3, DfMp3_PlaySources source) {
235 PrintlnSourceAction(source, "inserted");
236 }
237 static void OnPlaySourceRemoved([[maybe_unused]] DfMp3 &mp3, DfMp3_PlaySources source) {
238 PrintlnSourceAction(source, "removed");
239 }
240 };
241

242 //

50

243 //zmienne globalne
244 int score = 0;// wynik w grach
245 int hiScoreReactionTime = 0;//rekord w grze na czas reakcji 246 int hiScoreMemory = 0;//rekord w grze na pamięć
247 int choice = 6;//wybór zabawki
248
249 int light[4] = { 6, 7, 8, 9 };//przypisanie świateł 0-3 do pinów 250 int button[4] = { 2, 3, 4, 5 };//przypisanie przycisków 0-3 do pinów 251 int motor[4] = { 10, 11, 12, 13 };//przypisanie silników 0-3 do pinów 252

253 //
254 //funkcje urzytkownika
255 int whichButtonPressed() { //oczekuje na naciśnięcie przycisku i zwraca numer pierwszego naciśniętego
256 while (true) {
257 for (int i = 0; i < 4; i++) {
258 if (digitalRead(button[i]) == 0) { 259 delay(50);
260 if (digitalRead(button[i]) == 0) { 261 return i;
262 }
263 }
264 }
265 }
266 }
267 int memoryGame() { //gra pamięciowa
268 int sequence[maxGameLenght];
269 for (int i = 0; i < maxGameLenght; i++) {
270 sequence[i] = random(0, 4); //dodaj nowy element do sekfencji 271 delay(500);
272 //pokaż sekfejncę świateł i dźwięków
273 for (int k = 0; k <= i; k++) {
274 Serial.print(sequence[k]);
275 digitalWrite(light[sequence[k]], HIGH); 276 dfmp3.playFolderTrack(1, sequence[k] + 3); 277 delay(500);
278 digitalWrite(light[sequence[k]], LOW); 279 delay(100);
280 }
281
282 //sprawdź czy sekfencja została poprawnie oddtworzona

51

Kod programu

283 for (int k = 0; k <= i; k++) {
284 if (whichButtonPressed() != sequence[k]) { //jeżeli naciśnięto zły przycisk, zwróć wynik
285 dfmp3.playFolderTrack(1, 2);
286 return i;
287 }
288 digitalWrite(light[sequence[k]], HIGH); 289 dfmp3.playFolderTrack(1, sequence[k] + 3); 290 delay(200);
291 digitalWrite(light[sequence[k]], LOW);
292 }
293 //chwila przerwy by przejść dokolejnej iteracji 294 delay(1000);
295 dfmp3.playFolderTrack(1, 1);
296 delay(2000);
297 }
298 return 0;
299 }
300 int reactionTimeGame() { // gra na czas reakcji 301 //zmienne używane do obliczenia wyniku
302 unsigned long numenator = 3000000;
303 unsigned long denominator = 0;
304 for (int i = 0; i < 3; i++) {//trzykrotnie 305 //odliczanie
306 digitalWrite(light[0], 1);
307 digitalWrite(light[1], 1);
308 digitalWrite(light[2], 1); 309 digitalWrite(light[3], 1); 310 dfmp3.playFolderTrack(1, 7); 311 delay(1000);
312 digitalWrite(light[3], 0); 313 dfmp3.playFolderTrack(1, 7); 314 delay(1000);
315 digitalWrite(light[2], 0); 316 dfmp3.playFolderTrack(1, 7); 317 delay(1000);
318 digitalWrite(light[1], 0); 319 dfmp3.playFolderTrack(1, 7); 320 delay(1000);
321 digitalWrite(light[0], 0);
322 dfmp3.playFolderTrack(1, 7);
323 //po losowej przerwie zaświeć losowe światło 324 delay(random(500, 2000));
325 int whichLight = random(0, 4);
326 digitalWrite(light[whichLight], 1);
327 dfmp3.playFolderTrack(1, whichLight + 3); 328 unsigned long startTime = millis();

52

329 //jeżeli naciśnięto dobry przycisk dodaj czas reakcji do mianownika 330 if (whichButtonPressed() == whichLight) {
331 digitalWrite(light[whichLight], 0);
332 startTime = millis() - startTime;
333 dfmp3.playFolderTrack(1, 1);
334 denominator += startTime;
335 } else { // a jak zły, pomnóż dodatkowo razy 3 336 digitalWrite(light[whichLight], 0);
337 dfmp3.playFolderTrack(1, 2);
338 startTime = millis() - startTime;
339 denominator += startTime;
340 denominator *= 3;
341 }
342 delay(1000);
343 }
344 //zwróć wynik
345 int score = numenator / denominator; 346 return score;
347 }
348 //
349 void setup() {
350

351 Serial.begin(115200);
352 //inicjalizacja karty sd
353 Serial.print("Initializing SD card..."); 354 if (!SD.begin(SD_CS)) {
355 Serial.println("failed!");
356 return;
357 }
358 Serial.println("OK!");
359
360 //inicjalizacja ekranu 361 tft.initR(INITR_BLACKTAB);
362 tft.setRotation(1);
363 tft.setFont();
364 tft.fillScreen(Display_Backround_Color);
365 tft.setTextColor(Display_Text_Color);
366 tft.setTextSize(12);
367 isDisplayVisible = true; //powiedzenie wyświetlaczowi, że jest załączony 368 //
369 //inicjalizacja dfplayer mini
370 dfmp3.begin();
371 dfmp3.reset();
372
373 //
374 //ustawienie trybów pinów

53

Kod programu

375 pinMode(light[0], OUTPUT); 376 pinMode(light[1], OUTPUT); 377 pinMode(light[2], OUTPUT);
378 pinMode(light[3], OUTPUT);
379
380 pinMode(button[0], INPUT_PULLUP); 381 pinMode(button[1], INPUT_PULLUP); 382 pinMode(button[2], INPUT_PULLUP); 383 pinMode(button[3], INPUT_PULLUP); 384
385 pinMode(motor[0], OUTPUT);
386 pinMode(motor[1], OUTPUT);
387 pinMode(motor[2], OUTPUT); 388 pinMode(motor[3], OUTPUT); 389
390 pinMode(UP, OUTPUT);
391 pinMode(DOWN, OUTPUT); 392
393 pinMode(KEEP_ON, OUTPUT);
394
395 randomSeed(analogRead(POTENTIOMETER));
396
397 digitalWrite(KEEP_ON, 1); // załączenie tranzystora zwierającego masę 398 }
399
400 void loop() {
401 //zmienne potrzebne do operowania 402 int newScore;
403 int newChoice;
404 int bird;
405 int pic;
406 //wylosuj inny wybór niż był poprzednim razem 407 do {
408 newChoice = random(0, 8);
409 } while (newChoice == choice);
410 choice = newChoice;
411

412 switch (choice) { zależnie od zmiennej choice 413 case 0: // gra w pamięć
414 Serial.println("caase0");
415 //napisz dotychczasowy rekord
416 tft.setTextColor(Display_Text_Color); 417 tft.setTextSize(3);
418 tft.setCursor(5, 5);
419 tft.print("Rekord: ");
420

54

421 tft.setCursor(5, 29);
422
423 tft.print(hiScoreMemory);
424 score = memoryGame(); //zagraj grę
425
426 //wymaż ekran
427 tft.setTextColor(Display_Backround_Color); 428 tft.setCursor(5, 5);
429 tft.print("Rekord: ");
430 tft.setCursor(5, 29);
431 tft.print(hiScoreMemory);
432 tft.setCursor(5, 5);
433 tft.setTextColor(Display_Text_Color);
434 //jeżeli osiągnięto nowy rekord, napisz nowy rekord 435 if (score > hiScoreMemory) {
436 hiScoreMemory = score;
437 dfmp3.playFolderTrack(1, 8);
438 tft.print("nowy ");
439 tft.setCursor(5, 29);
440 tft.print("rekord: ");
441 tft.setCursor(5, 53);
442 tft.print(hiScoreMemory);
443 delay(4000);
444 tft.setCursor(5, 5);
445 tft.setTextColor(Display_Backround_Color); 446 tft.print("nowy ");
447 tft.setCursor(5, 29);
448 tft.print("rekord: ");
449 tft.setCursor(5, 53);
450 tft.print(hiScoreMemory); 451 } else { //jak nie, podaj wynik 452 tft.print(score);
453 delay(4000);
454 tft.setCursor(5, 5);
455 tft.setTextColor(Display_Backround_Color); 456 tft.print(score);
457 }
458

459 break;
460 | case 1: | //silnik 0 , fidget spinner
461 Serial.println("case 1");
462 digitalWrite(motor[0], 1);
463 digitalWrite(UP, 1);
464 delay(3000);
465 digitalWrite(UP, 0);
466 delay(2000);

55

Kod programu

467 digitalWrite(DOWN, 1); 468 delay(2500);
469 digitalWrite(DOWN, 0); 470 delay(2000);
471 digitalWrite(motor[0], 0); 472 break;
473 | case 2: | //silnik 1 wstążka
474 Serial.println("case 2"); 475 digitalWrite(motor[1], 1); 476 delay(2000);
477 digitalWrite(DOWN, 1); 478 delay(6000);
479 digitalWrite(DOWN, 0); 480 delay(2000);
481 digitalWrite(motor[1], 0);
482
483 break;
484 case 3: // silnik 2 skrzynia biegów 485 digitalWrite(motor[2], 1);
486 digitalWrite(UP, 1);
487 delay(2500);
488 digitalWrite(UP, 0);
489 delay(2000);
490 digitalWrite(DOWN, 1); 491 delay(2500);
492 digitalWrite(DOWN, 0); 493 delay(2000);
494 digitalWrite(motor[2], 0); 495
496 break;
497 case 4: // silik 3 klikacz 498 Serial.println("case 4"); 499 digitalWrite(motor[3], 1); 500 digitalWrite(UP, 1);
501 delay(2500);
502 digitalWrite(UP, 0);
503 delay(2000);
504 digitalWrite(DOWN, 1); 505 delay(2500);
506 digitalWrite(DOWN, 0); 507 delay(2000);
508 digitalWrite(motor[3], 0); 509 break;
510 case 5: // dopasowanie ptaków
511 Serial.println("case 5");
512 bird = random(1, 6); //wylosuj ptaka 513 dfmp3.playFolderTrack(2, bird);

56

514 digitalWrite(light[0], 1);
515 while (digitalRead(button[0]) == 1) { delay(100); } //czekaj na naciśnięci eprzycisku 0
516 // jeżeli potencjometr jest w dobrej pozycji, ogłoś sukces
517 if (analogRead(POTENTIOMETER) < 230 * bird - 55 && analogRead(POTENTIOMETER) > 230 * (bird - 1) - 55) {
518 dfmp3.playFolderTrack(1, 1);
519 } else {
520 dfmp3.playFolderTrack(1, 2); 521 }
522 digitalWrite(light[0], 0); 523 delay(1000);
524 break;
525
526 case 6: //gra w czas reakcji 527
528 Serial.println("caase6"); 529 //napisz dotychczasowy rekord
530 tft.setTextSize(3);
531 tft.setCursor(5, 5);
532 tft.setTextColor(Display_Text_Color); 533 tft.print("Rekord: ");
534 tft.setCursor(5, 29);
535
536 tft.print(hiScoreReactionTime);
537 score = reactionTimeGame(); //zagraj grę 538 //wymaż ekran
539 tft.setTextColor(Display_Backround_Color); 540 tft.setCursor(5, 5);
541 tft.print("Rekord: ");
542 tft.setCursor(5, 29);
543 tft.print(hiScoreReactionTime);
544 tft.setCursor(5, 5);
545 tft.setTextColor(Display_Text_Color);
546 //jeżeli osiągnięto nowy rekord, napisz nowy rekord 547 if (score > hiScoreReactionTime) {
548 hiScoreReactionTime = score;
549 dfmp3.playFolderTrack(1, 8);
550 tft.print("nowy ");
551 tft.setCursor(5, 29);
552 tft.print("rekord: ");
553 tft.setCursor(5, 53);
554 tft.print(hiScoreReactionTime);
555 delay(4000);
556 tft.setCursor(5, 5);
557 tft.setTextColor(Display_Backround_Color); 558 tft.print("nowy ");

57

Kod programu

559 tft.setCursor(5, 29);
560 tft.print("rekord: ");
561 tft.setCursor(5, 53);
562 tft.print(hiScoreReactionTime); 563 } else { // jak nie, podaj wynik 564 tft.print(score);
565 delay(4000);
566 tft.setCursor(5, 5);
567 tft.setTextColor(Display_Backround_Color); 568 tft.print(score);
569 }
570
571 break;
572
573 case 7: //wspomnienie
574 Serial.println("case 7");
575 pic = random(1, 4); //wylosuj jeden z 4 zestawów 576 dfmp3.playFolderTrack(3, pic); // zagraj dźwięk 577 switch (pic) { //wyświetl odpowiedni obraz
578 case 1:
579 bmpDraw("one.bmp", 0, 0);
580 break;
581 case 2:
582 bmpDraw("two.bmp", 0, 0); 583 break;
584 case 3:
585 bmpDraw("three.bmp", 0, 0); 586 break;
587 case 4:
588 bmpDraw("four.bmp", 0, 0); 589 break;
590 }
591

592 //czekaj aż dźwięk się skończy
593 while (dfmp3.getStatus().state & 0x01) {
594 dfmp3.loop(); // Process incoming DFPlayer messages 595 delay(200);
596 Serial.println("waiting");
597 }
598 tft.fillScreen(Display_Backround_Color); 599 break;
600 }
601 }
602
603 void setup1() {
604 //czekaj aż pierwszy rdzeń skończy inicjalizację

58

605 delay(3000);
606 }
607 void loop1() {
608 //jeżeli napięcie spadnie poniżej 3V/celę, zagraj dźwięk ostrzegawczy 609 if (analogRead(VOLTAGE) < 370) {
610 dfmp3.playFolderTrack(1, 9);
611 delay(30000);
612 }
613 //jeżeli napięcie spadnie poniżej 2,7V na celę, wyłącz układ 614 if (analogRead(VOLTAGE) <= 330) {
615 Serial.println("off1");
616 pinMode(KEEP_ON, INPUT);
617 }
618 //jeżeli wszystkie guziki są przytrzymane przez 5 sekund, również wyłącz 619 if (digitalRead(button[0])== 0&&digitalRead(button[1])== 0&&digitalRead(button[2])== 0&&digitalRead(button[3])== 0) {
620 delay(5000);
621 if (digitalRead(button[0])== 0&&digitalRead(button[1])== 0&&digitalRead(button[2])== 0&&digitalRead(button[3])== 0) { 622 tft.print("rip ");
623 delay(500);
624
625 Serial.println("off2"); 626 pinMode(KEEP_ON, INPUT); 627 }
628 }
629 delay(1000);
630 }

59

Kosztorys

## Kosztorys

Element | ilość | cena
Obudowa | 1 | 300,00 zł
Płytka PCB | 5 | 40,00 zł
Raspberry Pi PICO H | 1 | 25,90 zł
DFPlayer mini | 1 | 27,90 zł
Listwy goldpin żeńskie | 10 | 9,90 zł
Listwy goldpin męskie | 2 | 1,70 zł
Gniazda JST2 | 13 | 13,00 zł
Wtyki JST 2 | 13 | 17,75 zł
Przycisk z podświetleniem 4 | 32,00 zł
Moduł ładowania USB C | 1 | 19,90 zł
Koszyk na ogniwa | 1 | 4,50 zł
Ogniwa li-ion 18650 | 2 | 14,96 zł
Silnik szczotkowy | 4 | 30,88 zł
Moduł L293D | 2 | 6,00 zł
Głośnik 3W | 1 | 6,36 zł
Moduł ULN 2003 | 1 | 3,90 zł
Przewód 2x1,5mm | 2mb 6,38 zł
Filament PLA+ | 1kg | 50,00 zł
Moduł SD | 1 | 1,00 zł
Karta micro SD 16Gb | 2 | 35,80 zł
Klej na gorąco | 1kg | 23,50 zł
Taśma montażowa | 1 | 22,98 zł
Wyświetlacz LCD TFT | 1 | 39,00 zł
Mosfet kanał N | 1 | 3,98 zł
Stabilizator 5V | 1 | 1,50 zł
Rezystory | 7 | 6,20 zł
Łożysko kulkowe | 1 | 1,60 zł
SUMA | | 746,59 zł

60

## Karta czasu realizacji

lp.Czynność | Czas .
1 Powstanie pomysłu na projekt | 01.2024r.
2 Badanie niszy | 01-02.2024r.
3 Kształtowanie założeń projektu | 02.2024r.
4 Testy na płytce prototypowej | 02-04.2024r.
5 Projektowanie płytki PCB | 04.-052024r.
6 Projektowanie elementów mechanicznych 3D | 05-06.2024r.
7 Pierwszy Prototyp | 06.2024r.
8 Testy prototypu, aktualizacja założeń | 06-09.2024r.
9 Projektowanie obudowy | 09.-102024r.
10Projektowanie Pozostałych elementów 3D | 10.2024r.-01.2025r.
11 Testy w finalnej obudowie | 01-02.2025r.
12Dodawanie funkcji do kodu | 02.2025r.
13Wizualizacja i dokumentacja | 02-03.2025r.

## Podsumowanie

Budując nasz projekt napotkaliśmy się na szereg trudności związanych z łączeniem poszczególnych podzespołów elektroniczno-elektrycznych. Nie obyło się bez spalonych układów. Trudno też jednoznacznie ocenić czas poświęcony na pisanie programu liczony setkach spędzonych minut oraz nieprzespanych nocy. Jednak mimo tych przeciwności jesteśmy dumni z tego, że doprowadziliśmy projekt do końca. Działa on według wstępnych założeń. A co nas najbardziej podbudowało to fakt, że po przekazaniu go do testowania dla pacjenta okazało się, że miło spędził czas ćwicząc na naszym „Dementusie”, pacjent pozytywnie ocenił również fakt , że poszczególnym ćwiczeniu chowa się ono do obudowy dzięki czemu mamy jednoznaczność co do wykonania ćwiczenia ponieważ tylko ono wyjeżdża i znajduje się nad obudową. Dalej planujemy rozwijać nasz projekt. Podczas testowania pacjenci zwrócili uwagę, że wyświetlacz mógłby być większy, dlatego w następnej wersji zostanie wyświetlacz zwiększony. Pragniemy również zwiększyć funkcjonalność urządzenia wzbogacając go o dodatkowe ćwiczenia.

61

## Galeria

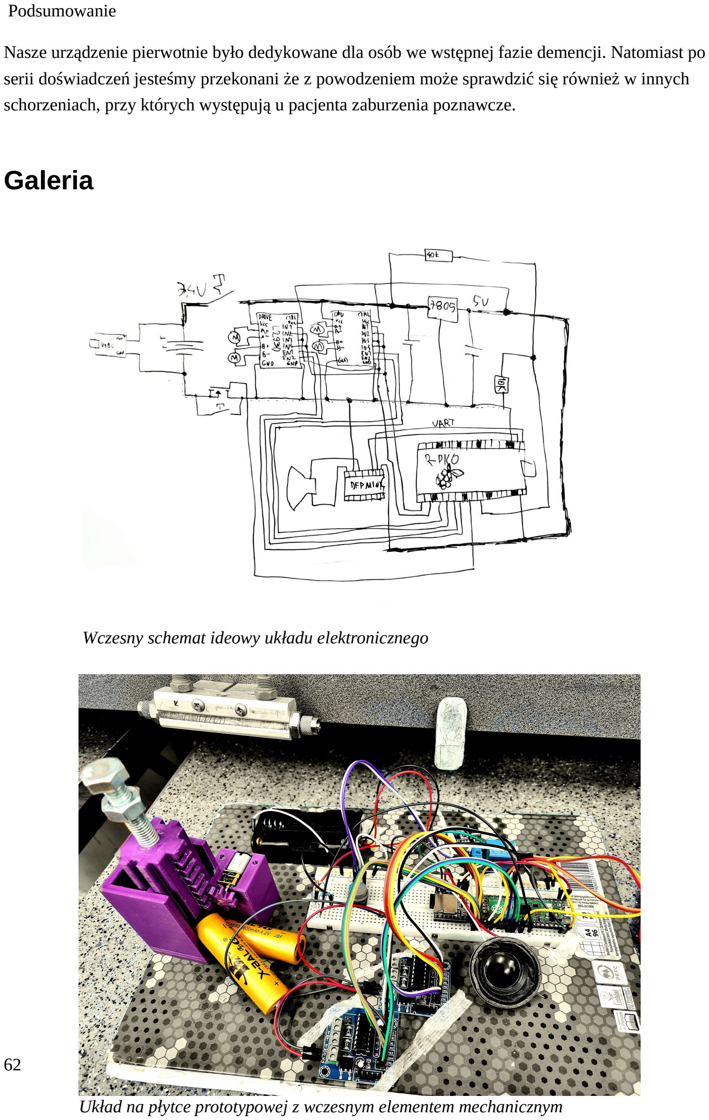
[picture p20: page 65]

Podsumowanie

Nasze urządzenie pierwotnie było dedykowane dla osób we wstępnej fazie demencji. Natomiast po serii doświadczeń jesteśmy przekonani że z powodzeniem może sprawdzić się również w innych schorzeniach, przy których występują u pacjenta zaburzenia poznawcze.

62

Wczesny schemat ideowy układu elektronicznego

Układ na płytce prototypowej z wczesnym elementem mechanicznym

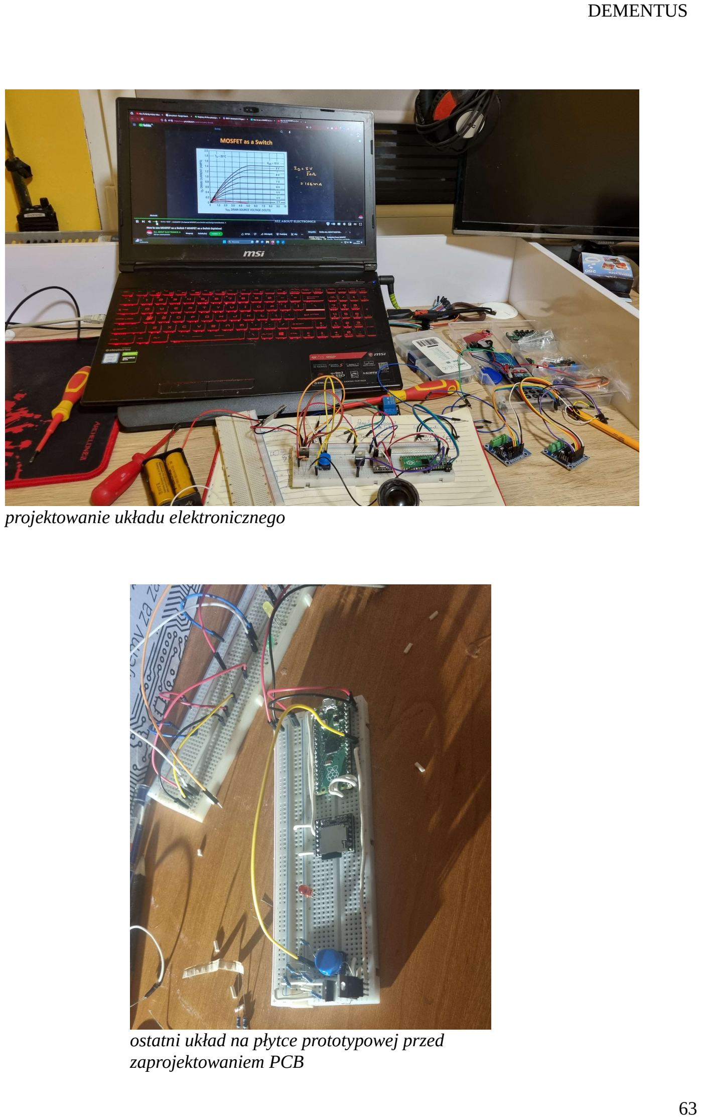
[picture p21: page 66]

63

projektowanie układu elektronicznego

ostatni układ na płytce prototypowej przed zaprojektowaniem PCB

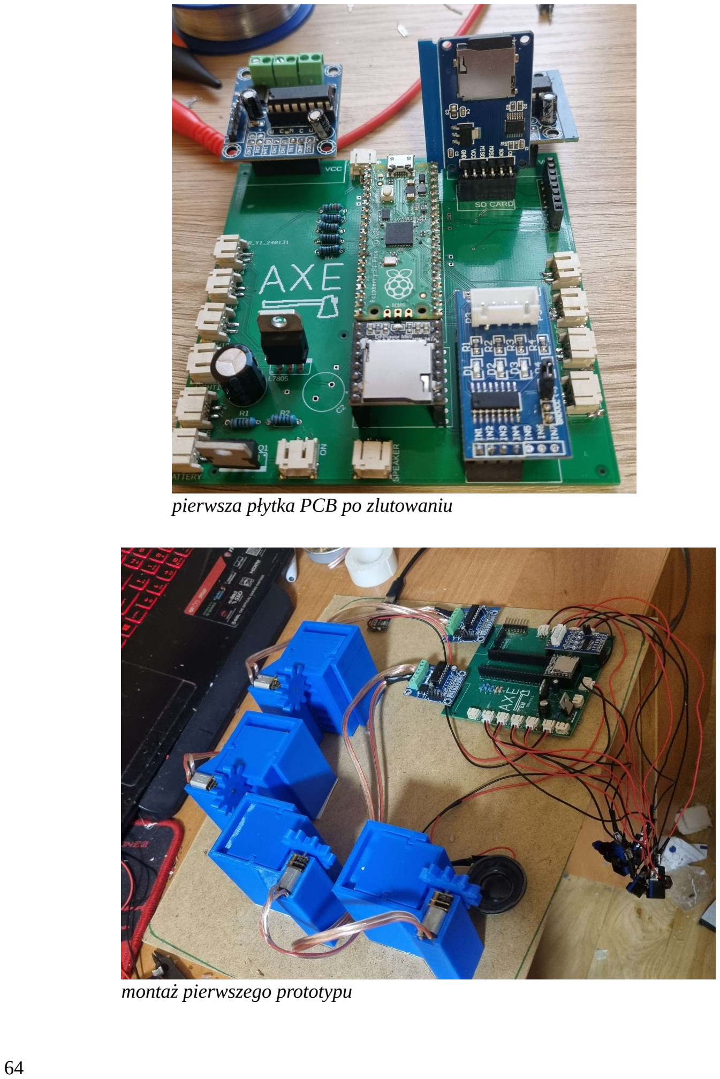
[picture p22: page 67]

64

pierwsza płytka PCB po zlutowaniu

montaż pierwszego prototypu

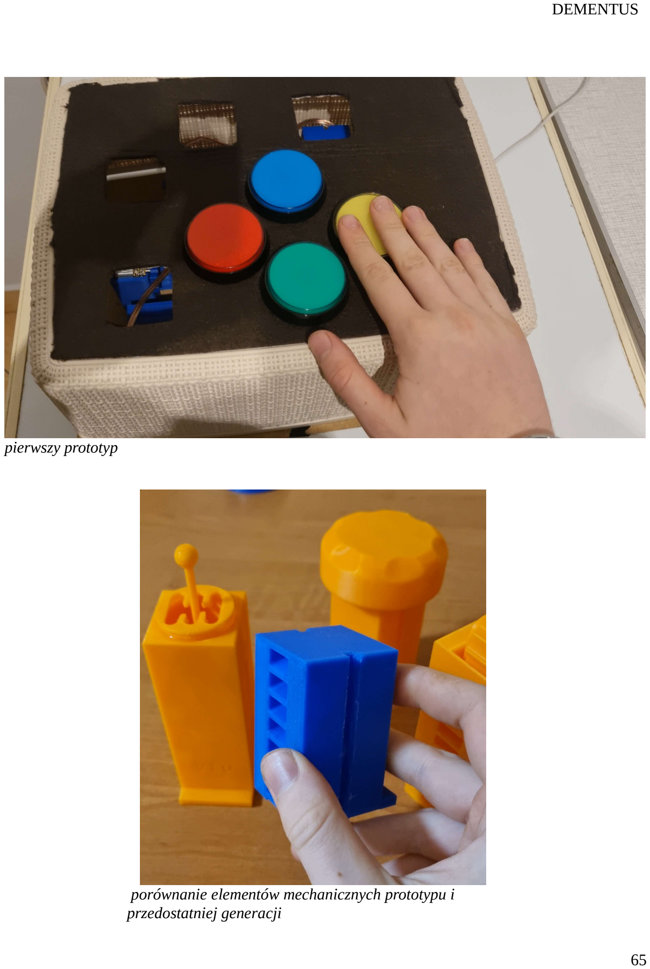
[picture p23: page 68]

65

pierwszy prototyp

porównanie elementów mechanicznych prototypu i przedostatniej generacji

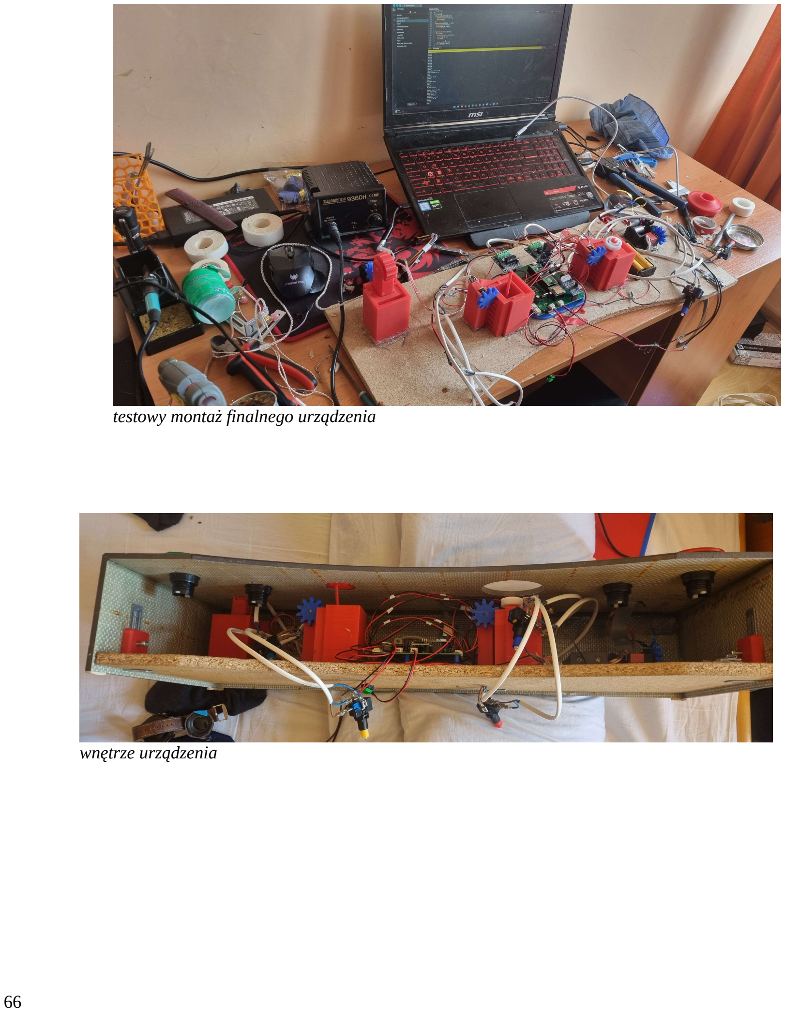
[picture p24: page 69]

66

testowy montaż finalnego urządzenia

wnętrze urządzenia

67

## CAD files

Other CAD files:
PCB/CHECK_v2.f3d
PCB/Ksztalt_v3.f3d
PCB/pcb 3d_v10.f3d
Pliki 3d/FIanl parts/Body front_v6.f3d
Pliki 3d/FIanl parts/Pistons/Base Piston_v6.f3d
Pliki 3d/FIanl parts/Pistons/Spinny piston_v4.f3d
Pliki 3d/FIanl parts/Pistons/button_v1.f3d
Pliki 3d/FIanl parts/Pistons/clicker piston_v3.f3d
Pliki 3d/FIanl parts/Pistons/new base piston_v1.f3d
Pliki 3d/FIanl parts/Pistons/shifter piston_v2.f3d
Pliki 3d/FIanl parts/Pistons/shifter_v2.f3d
Pliki 3d/FIanl parts/Pistons/shifty_v2.f3d
Pliki 3d/FIanl parts/Pistons/spinny bit_v7.f3d
Pliki 3d/FIanl parts/bird thing_v1.f3d
Pliki 3d/FIanl parts/pcb holder_v2.f3d
Pliki 3d/FIanl parts/print1_v1.f3d
Pliki 3d/FIanl parts/shifter bracket_v1.f3d
Pliki 3d/FIanl parts/side bracker_v1.f3d
Pliki 3d/Mockup/Drawing2_v2.f3d
Pliki 3d/Mockup/clicker_v2.f3d
Pliki 3d/Mockup/clicky_v1.f3d
Pliki 3d/Mockup/holder for clicker_v3.f3d
Pliki 3d/Mockup/holder for shifter_v4.f3d
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

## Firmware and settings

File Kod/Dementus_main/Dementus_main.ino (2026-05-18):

// Dementus v1.0
//
// You need to modify Adafruit ST7735 library. to do that copy offset lines from init greentab and paste them to init blacktab
// analogRead goes from 0 to 1023
// digitalRead(BUTTON_1)==1 means button not pressed.
//


//general defining of pins

 //Uart used to communicate with dfplayer mini
  #define UART_RX 0
  #define UART_TX 1
 //
 //backup button control
  #define  BUTTON_1 2
  #define BUTTON_2 3
  #define BUTTON_3 4
  #define BUTTON_4 5
 //
 //backup light control
  #define LIGHT_1 6
  #define LIGHT_2 7
  #define LIGHT_3 8
  #define LIGHT_4 9
 // 
 //backup motor control
  #define MOTOR_1 10
  #define MOTOR_2 11
  #define MOTOR_3 12
  #define MOTOR_4 13
 //
 //direction of movement of chosen motors
  #define UP 15
  #define DOWN 14
 //
 //analog pins
  #define POTENTIOMETER 26 // analog pin, checks position of potentiometer 
  #define VOLTAGE 28 // analog pin, checks battery voltage 
  #define KEEP_ON 27 // keeps mosftet on, if turned to input mode, will turn off the device
 //
 //pins needed to operate LCD screen
  #define LCD_BACKLIGHT 22
  #define LCD_DC 21
  #define LCD_CS 20
  #define TFT_CS        20 // Hallowing display control pins: chip select
  #define TFT_RST       37 // Display reset
  #define TFT_DC        21 // Display data/command select
  #define TFT_BACKLIGHT  22 // Display backlight pin
  #define SerialDebugging true
 //
 //pins needed for SD card
  #define SD_CS 17
 //
 //SPI pins
  #define MOSI 19
  #define MISO 16
  #define CLK  18
 
//
// constants
 #define maxGameLenght 100 // limits lenght of memory game
//
//stuff for lcd text display

 #include <Adafruit_GFX.h>    // Core graphics library
 #include <Adafruit_ST7735.h> // Hardware-specific library for ST7735
 #include <SPI.h>

 Adafruit_ST7735 tft = Adafruit_ST7735(TFT_CS,  TFT_DC, TFT_RST);


 // color definitions
  const uint16_t  Display_Color_Black        = 0x0000;
  const uint16_t  Display_Color_Blue         = 0x001F;
  const uint16_t  Display_Color_Red          = 0xF800;
  const uint16_t  Display_Color_Green        = 0x07E0;
  const uint16_t  Display_Color_Cyan         = 0x07FF;
  const uint16_t  Display_Color_Magenta      = 0xF81F;
  const uint16_t  Display_Color_Yellow       = 0xFFE0;
  const uint16_t  Display_Color_White        = 0xFFFF;
 //
 // The colors we actually want to use
  uint16_t        Display_Text_Color         = Display_Color_Black;
  uint16_t        Display_Backround_Color    = Display_Color_Blue;
 //
 // assume the display is off until configured in setup()
  bool            isDisplayVisible        = false;
 //
 // declare size of working string buffers. Basic strlen("d hh:mm:ss") = 10
  const size_t    MaxString               = 16;
 //
//
// stuff for DFPlayer mini
  #include <DFMiniMp3.h>
 
 // forward declare the notify class, just the name
 //
 class Mp3Notify; 

 // define a handy type using serial and our notify class
 //
 typedef DFMiniMp3<HardwareSerial, Mp3Notify> DfMp3; 

 // instance a DfMp3 object, 
 //
 DfMp3 dfmp3(Serial1);
 class Mp3Notify
 {
 public:
   static void PrintlnSourceAction(DfMp3_PlaySources source, const char* action)
   {
     if (source & DfMp3_PlaySources_Sd) 
     {
         Serial.print("SD Card, ");
     }
     if (source & DfMp3_PlaySources_Usb) 
     {
         Serial.print("USB Disk, ");
     }
     if (source & DfMp3_PlaySources_Flash) 
     {
         Serial.print("Flash, ");
     }
     Serial.println(action);
   }
   static void OnError([[maybe_unused]] DfMp3& mp3, uint16_t errorCode)
   {
     // see DfMp3_Error for code meaning
     Serial.println();
     Serial.print("Com Error ");
     Serial.println(errorCode);
   }
   static void OnPlayFinished([[maybe_unused]] DfMp3& mp3, [[maybe_unused]] DfMp3_PlaySources source, uint16_t track)
   {
     Serial.print("Play finished for #");
     Serial.println(track);  
   }
   static void OnPlaySourceOnline([[maybe_unused]] DfMp3& mp3, DfMp3_PlaySources source)
   {
     PrintlnSourceAction(source, "online");
   }
   static void OnPlaySourceInserted([[maybe_unused]] DfMp3& mp3, DfMp3_PlaySources source)
   {
     PrintlnSourceAction(source, "inserted");
   }
   static void OnPlaySourceRemoved([[maybe_unused]] DfMp3& mp3, DfMp3_PlaySources source)
   {
     PrintlnSourceAction(source, "removed");
   }
 };
//
//global variables
 int score;

 int light[4] = {6,7,8,9};
 int button[4] = {2,3,4,5};
 int motor[4] = {10,11,12,13};
//
//functions
 int whichButtonPressed(){
   while(true){
     for(int i=0; i<4; i++){
       if(digitalRead(button[i])==0){
         delay(50);
         if(digitalRead(button[i])==0){
           return i;
         }
       }
     }
   }
 }
 int memoryGame(){
   int sequence[maxGameLenght];
   for(int i=0; i<maxGameLenght; i++){
     sequence[i]=random(0,4);
     delay (500);
     //show sequence of lights
     for(int k=0; k<=i; k++){
       Serial.print(sequence[k]);
       digitalWrite(light[sequence[k]], HIGH);
       dfmp3.playFolderTrack(1, sequence[k]+3);
       delay(500);
       digitalWrite(light[sequence[k]], LOW);
       delay(100);
     }

     //check if sequence was memorised properly
     for(int k=0; k<=i; k++){
       if(whichButtonPressed()!=sequence[k]){
         dfmp3.playFolderTrack(1, 2);
         return i ;
       }
       digitalWrite(light[sequence[k]], HIGH);
       dfmp3.playFolderTrack(1, sequence[k]+3);
       delay(200);
       digitalWrite(light[sequence[k]], LOW);
     }
     delay(1000);
     dfmp3.playFolderTrack(1, 1);
     delay(2000);

   }
   return 0 ;
 }
//
//
void setup() {

 
 Serial.begin(9600); 

 //initialise lcd screen
  tft.initR(INITR_BLACKTAB);
  tft.setRotation(1);
   tft.setFont();
   tft.fillScreen(Display_Backround_Color);
   tft.setTextColor(Display_Text_Color);
   tft.setTextSize(12);
  // the display is now on
  isDisplayVisible = true;
 //
 //DFPLayer mini
  dfmp3.begin();
  dfmp3.reset();

 //
 //pinModes
  pinMode(light[0],OUTPUT);
  pinMode(light[1],OUTPUT);
  pinMode(light[2],OUTPUT);
  pinMode(light[3],OUTPUT);

  pinMode(button[0],INPUT_PULLUP);
  pinMode(button[1],INPUT_PULLUP);
  pinMode(button[2],INPUT_PULLUP);
  pinMode(button[3],INPUT_PULLUP);

  pinMode(motor[0],OUTPUT);
  pinMode(motor[1],OUTPUT);
  pinMode(motor[2],OUTPUT);
  pinMode(motor[3],OUTPUT);

  pinMode(UP,OUTPUT);
  pinMode(DOWN,OUTPUT);

  pinMode(KEEP_ON,OUTPUT);
 
 randomSeed(analogRead(POTENTIOMETER));

 digitalWrite(KEEP_ON,1); // keeps ground connected when using battery
 // pinMode(KEEP_ON, INPUT);
}

void loop() {
 Serial.println(analogRead(POTENTIOMETER));
 delay(500)
;
 }
 
